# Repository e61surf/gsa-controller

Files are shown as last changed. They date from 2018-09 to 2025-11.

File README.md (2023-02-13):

# Surf System Controller - or whatever you want to control...

Feel free to make use of the hardware and software designs here for your project. It is ideally suited for robotics, small electric mobility decives, linear actuator control, or basically anything that needs to drive somewhat high-current motors and needs GPS and Bluetooth. The Atmel 32u4 based, high current board design utilizes:
3 ST Micro motor drivers,
1 Lynx GPS Module, and
1 Microchip BLE Module.

It is designed to fit into a Cinch ModeICE enclosure, which is fully waterproof.

The hardware/software design supports up to a 10 wire, 5 volt control cable and is currently utlizing 2 potentiometers, 3 momentary switches, and 3 LED indicators, but the Atmel 32u4 processor pins can be utlized for many different perposes. 

It can drive up to 3 12v motors/actuators.  Or one of the ST Micro chips can be configured as two 12v outputs for lights, horns, etc...

The board is designed to run on 12v power from a marine or automotive alternator, so it'll handle fluctuations and noise typical in rugged applications.

The BLE module and supporting AVR code supports a custom framed serial protocol for control via a mobile app.  See the documents for more info.

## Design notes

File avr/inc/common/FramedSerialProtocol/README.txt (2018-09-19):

Framed Serial Protocol Info
-------------

Message Structure (bi-directional):
Segment				Length			Notes
------------------------------------------------
Frame start			1 byte (0x7e)
Length				1 byte			Length of packet from command to end of payload inclusive
Command				1 byte
Payload				0 - 254 bytes
Checksum			1 byte			8-bit sum of all unescaped bytes from command to end of payload inclusive subtracted from 0xFF.  I.e. if if the sum is 0x02, the checksum would be 0xFD.

Note that if any byte from Length to Checksum (inclusive) matches the Frame Start or Escape bytes, then it must be escaped.
Escaping is accomplished by writing the escape character (0x7d) followed by the byte which needs escaping XOR'd with 0x20.

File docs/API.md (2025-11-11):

# SurfControl Firmware API

This document describes the public interfaces exposed by the SurfControl AVR firmware. It covers the application entry points, messaging contracts, hardware abstraction classes, and supporting utility libraries. Each section calls out responsibilities, configuration options, and example usage patterns.

## Quick Start
- **Initialization**: Call `setup()` once after reset to configure hardware, load persisted settings, and initialize communications.
- **Main loop**: Repeatedly call `loop()`; it orchestrates input sampling, actuator control, messaging, and safety logic.
- **Polling**: Every hardware abstraction (`Actuator`, `Buttons`, `Output`, `Gps`) requires periodic `poll()` calls with the elapsed milliseconds since the previous invocation.
- **Serial ISR**: Provide an `ISR(USART1_RX_vect)` that calls `serialAvr.isr()` so UART1 receive events reach the BLE link.
- **Watchdog**: The firmware expects the watchdog timer to run; `loop()` regularly resets it.

```c++
#include "SurfControl.h"

int main() {
  setup();
  while (true) {
    loop();
  }
}
```

## Application-Level API (`SurfControl.h`)

### System Configuration Constants
- **EEPROM layout**: `EEPROM_OFFSET` defines the starting address for persisted configuration; offsets 1-4 store center-motor enable, demo mode, wake-transfer delay, and actuator extension time.
- **Speed thresholds**: `MAX_SPEED` and `CENTER_EXTEND_SPEED` gate automatic tab movements based on GPS speed.
- **I/O wiring**: `BUTTON*`, `LED_*`, and `MOTOR_*` macros map AVR ports/pins to buttons, LEDs, and H-bridge channels.

### Operating Modes
- `MODE_READY` — Idle state awaiting input.
- `MODE_AUTOMATIC_CHANGE` — Automatic transitions (launch/reset/auto-trim) in progress.
- `MODE_MANUAL_RETRACT_PORT` / `MODE_MANUAL_RETRACT_STARBOARD` — Manual retraction while corresponding button combination is held.
- `MODE_MANUAL_EXTEND_PORT` / `MODE_MANUAL_EXTEND_STARBOARD` — Manual extension while button is held.

### Actuator, Direction, and Potentiometer Identifiers
- `ACTUATOR_PORT`, `ACTUATOR_STARBOARD`, `ACTUATOR_CENTER` — Select specific tab actuators when encoding BLE messages.
- `DIRECTION_DOWN`, `DIRECTION_UP` — Specify trim direction for potentiometer adjustments.
- `POT_1`, `POT_2` — Identify digital potentiometer channels when using `MSG_POT` or `MSG_POT_TRIM`.

### Message Protocol
Incoming and outgoing BLE messages use framed serial packets (see `FramedSerialProtocol`). Command identifiers and payload shapes are defined via `MSG_*` macros:

| Command | Payload | Usage |
| --- | --- | --- |
| `MSG_RESET` | none | Retract port/starboard actuators; conditionally extend center tab. |
| `MSG_LAUNCH` | none | Fully extend both actuators for launch. |
| `MSG_SURF_LEFT` / `MSG_SURF_RIGHT` | none | Enter surf mode (requires full retraction). |
| `MSG_MANUAL_RETRACT` / `MSG_MANUAL_EXTEND` | `[Actuator]` | Adjust selected actuator by ±5%. |
| `MSG_POT` | `[Pot Index][Pot Value]` | Set digital potentiometer target. |
| `MSG_POT_TRIM` | `[Pot Index][Direction]` | Trim potentiometer relative to current value. |
| `MSG_SCHEDULE_WAKE_TRANSFER` | none | Queue wake-transfer (valid in surf modes). |
| `MSG_DEBUG` | ASCII text | Emitted by firmware for diagnostics. |
| `MSG_STATE` | `[Mode][Port%][Starboard%][Center%][Pot1][Pot2][GpsLock][GpsSpeed][WakeTransferTimer]` | Periodic state broadcast; request by sending command with no data. |
| `MSG_CURRENT_SENSE` | `[PortCS][StarboardCS][CenterCS]` | Current-sense snapshot (8-bit values). |
| `MSG_GET_CONFIG` | none | Request persisted configuration; device responds with same command and 4 data bytes. |
| `MSG_SET_CONFIG` | `[CenterMotor][DemoMode][WakeTransferDelay][FullExtensionTime]` | Persist new configuration and reset MCU. |
| `MSG_LEGACY` | `[LegacyCommand]` | Compatibility command forwarded as-is. |

### Bluetooth Bootstrap
- `void bluetooth_init();` — Initializes the RN4870 BLE module to transparent serial mode. Internally issues command-mode strings via `bluetooth_command()` and drains responses.

### Entry Points
- `void setup();` — Hardware initialization, EEPROM load, analog setup, and peripheral bootstrap.
- `void loop();` — Main control loop (state machine, messaging, actuator logic).

> **Note:** `bluetooth_command()` is file-local; only `bluetooth_init()` is exposed in the header.

## Actuator Control (`Actuator.h`)

`Actuator` encapsulates a single linear actuator with PWM control and run-time tracking.

### Constructor
```c++
Actuator::Actuator(volatile uint8_t *port1,
                   uint8_t pin1,
                   volatile uint8_t *port2,
                   uint8_t pin2,
                   volatile uint8_t *portPwm,
                   uint8_t pinPwm,
                   uint8_t csAdc);
```

- `port1`/`pin1` and `port2`/`pin2` control H-bridge direction pins.
- `portPwm`/`pinPwm` drives the PWM enable line.
- `csAdc` indexes the analog current-sense channel.
- Automatically configures DDR and sets outputs low; initializes full-extension time to 3.5 s.

### Runtime API
- `void poll(uint16_t elapsed_ms);` — Drives the H-bridge according to pending extend/retract durations or manual override, using elapsed time since the previous call.
- `void set_extension(int8_t percent);` — Schedule actuator to reach a target position (0–100%). Clamps input, compensates for motor spin-up, and adjusts calibration when operating at limits.
- `void adjust_extension(int8_t delta_percent);` — Convenience wrapper around `set_extension(get_extension() + delta_percent)`.
- `uint8_t get_extension();` — Estimates current extension (0 or 100 returned when near extremes, otherwise 5–98% range).
- `void set_manual_movement(int8_t movement);` — Direct control: `1` extends, `-1` retracts, `0` disables manual override. Manual motion continues until cleared.
- `int32_t get_outstanding_time();` — Remaining movement in milliseconds (positive for extension, negative for retraction).
- `uint32_t get_full_extension_time();` / `void set_full_extension_time(uint16_t ms);` — Retrieve or configure travel time (clamped to 3000–8000 ms).

### Usage Example
```c++
Actuator trim(&PORTB, 2, &PORTB, 3, &PORTD, 6, POT1_ADC);

void service_actuator(uint16_t elapsed_ms) {
  trim.poll(elapsed_ms);
  if (need_full_extension && trim.get_extension() < 95) {
    trim.set_extension(100);
  }
}
```

## Button Handling (`Buttons.h`)

`Buttons` debounces and classifies up to three physical buttons.

### Constructor
```c++
Buttons::Buttons(volatile uint8_t *port1, uint8_t pin1,
                 volatile uint8_t *port2, uint8_t pin2,
                 volatile uint8_t *port3, uint8_t pin3);
```

- Configures pins as inputs with pull-ups.
- Button indices (`BUTTON_SURF_LEFT`, `BUTTON_RESET`, `BUTTON_SURF_RIGHT`) map into the event masks returned by accessors.

### Polling & Queries
- `void poll(uint16_t elapsed_ms);` — Sample inputs, update timers, and derive edge/hold states.
- `uint8_t falling_edge();` — Buttons newly pressed (held longer than `PRESS_TIME` without prior release).
- `uint8_t rising_edge();` — Buttons newly released after a qualifying press.
- `uint8_t longpressed();` — Buttons surpassing `LONGPRESS_TIME` without release.
- `uint8_t held();` — Buttons currently held beyond long-press threshold; used for continuous manual modes.

### Usage Example
```c++
Buttons controls(&PORTF, 0, &PORTB, 0, &PORTB, 1);

void service_buttons(uint16_t elapsed_ms) {
  controls.poll(elapsed_ms);
  if (controls.falling_edge() & _BV(BUTTON_RESET)) {
    trigger_reset_sequence();
  }
  if (controls.held() & _BV(BUTTON_SURF_LEFT)) {
    actuatorPort.set_manual_movement(1);
  }
}
```

## Output Control (`Output.h`)

`Output` manages a single digital output with on/off/flash states.

- Constructor: `Output(volatile uint8_t *port, uint8_t pin);` — Sets DDR and initializes pin low.
- `void poll(uint16_t elapsed_ms);` — Applies current flash state: off (`0x0000`), solid on (`0xFFFF`), or toggling at configured interval.
- `void on();`, `void off();`, `void flash(uint16_t interval_ms);` — Queue desired state changes, applied on next `poll()`.

### Usage Example
```c++
Output statusLed(&PORTB, 7);

void indicate_status(uint16_t elapsed_ms, bool critical) {
  if (critical) statusLed.flash(200);
  else statusLed.on();
  statusLed.poll(elapsed_ms);
}
```

## GPS Wrapper (`Gps.h`)

Provides a thin layer over `TinyGPS` for speed and lock status tracking.

- Constructor: `Gps();` (the actual serial configuration must occur in user code).
- `void poll(uint16_t elapsed_ms);` — Reads bytes via `software_serial_*` helpers, feeds the TinyGPS parser, and tracks time since last valid sentence (`GPS_TIMEOUT` defines the lock threshold).
- `uint8_t get_locked();` — Returns `1` when valid sentences arrive within timeout, `0` otherwise. Always `1` in demo mode.
- `uint8_t get_speed();` — Last parsed speed in knots (integer). Returns `9` in demo mode.

### Usage Example
```c++
Gps gps;

void update_gps(uint16_t elapsed_ms) {
  gps.poll(elapsed_ms);
  if (!gps.get_locked()) {
    enter_fail_safe();
  }
}
```

## Analog Utilities (`lib/analog/analog.h`)

- `void analog_init(uint8_t analog_pins[], uint8_t count, uint8_t aref);` — Configure ADC channels. `aref` accepts `ANALOG_AREF`, `ANALOG_AVCC`, or `ANALOG_INTERNAL_256` constants.
- `void analog_read_a(uint16_t *buffer);` — Fill `buffer` with current values for the configured channel sequence.
- `uint16_t analog_read_p(uint8_t index);` — Read a single configured channel synchronously.

Ensure `F_CPU` matches the MCU clock (16 MHz in this project) so default prescaler values yield accurate conversions.

## Timer Utilities (`lib/timer/timer.h`)

- `void timer_init();` — Configure Timer1 in CTC mode for 1 kHz interrupts (automatic `sei()` unless `NO_INTERRUPT_ENABLE` is defined).
- `uint32_t timer_millis();` — Milliseconds since initialization (wraps ~49 days).
- `uint32_t timer_micros();` — Microseconds since initialization (wraps ~71 minutes).

Use `timer_millis()` to compute elapsed times for `poll()` calls.

## Software Serial (`lib/serial/software_serial.h`)

Implements half-duplex software UART on PD0 (TX) / PD1 (RX) with interrupt-driven receive.

- `void software_serial_init(uint32_t baud);` — Supported baud rates: 9600 (default) or 115200 (TX only). Requires 16 MHz system clock.
- `uint8_t software_serial_read_b(uint8_t *byte);` — Non-blocking read; returns 1 when a byte is available.
- `void software_serial_write_a(uint8_t *data, uint8_t len);` — Blocking write of a byte buffer.
- `uint8_t software_serial_write_b(uint8_t data);` — Blocking single-byte write.
- `uint8_t software_serial_available();` — Returns non-zero when receive buffer contains data.

Example: Poll within the GPS service loop before feeding characters to `TinyGPS`.

## Hardware Serial (`inc/avr/Serial/SerialAVR.h`)

`digitalcave::SerialAVR` adapts AVR hardware UARTs to the `Stream` interface.

- Constructor signature:
  ```c++
  SerialAVR(uint32_t baud,
            uint8_t dataBits = 8,
            uint8_t parity = 0,
            uint8_t stopBits = 1,
            uint8_t serialPort = 0,
            uint8_t bufferSize = 64);
  ```
  - `serialPort`: 0 → USART0, 1 → USART1 (additional ports can be added).
  - Constructor enables RX interrupts and TX output using double-speed mode when beneficial.
- `uint8_t read(uint8_t *b);` — Non-blocking; disables RX interrupt temporarily to protect the ring buffer.
- `uint8_t write(uint8_t data);` — Blocking transmit.
- `void isr();` — Must be invoked from the corresponding UART RX ISR to push incoming bytes into the buffer.

### Usage Example
```c++
SerialAVR serialAvr(115200, 8, 0, 1, 1, 128);

ISR(USART1_RX_vect) {
  serialAvr.isr();
}
```

## USB Serial (`inc/avr/Serial/SerialUSB.h`)

`digitalcave::SerialUSB` exposes CDC ACM over USB (Teensy-compatible implementation).

- Constructor: `SerialUSB();` — Configures USB hardware, enables interrupts, and starts the CDC stack.
- `uint8_t isConnected();` — Non-zero when USB host has enumerated the device.
- `uint8_t available();` — Count of buffered bytes in RX endpoint.
- `void flushInput();`, `void flushOutput();` — Clear buffers and force immediate transmission.
- `uint8_t read(uint8_t *b);`, `uint8_t write(uint8_t data);`, `uint8_t write(uint8_t* data, uint8_t len);` — Stream operations (all non-blocking for reads, blocking for writes as required by USB semantics).

Standalone C helpers (e.g., `usb_init`, `usb_serial_write_b`) mirror PJRC's API for legacy code.

## Stream Abstractions (`inc/common/Stream`)

- `digitalcave::Stream` — Abstract base class defining `read(uint8_t*)` and `write(uint8_t)` plus utility overloads:
  - `uint8_t read(uint8_t* buffer, uint8_t len);`
  - `uint8_t write(char* data);`
  - `uint8_t write(const char* data);`
  - `uint8_t write(uint8_t* data, uint8_t len);`

- `digitalcave::ArrayStream` — Ring buffer implementation:
  - `ArrayStream(uint8_t capacity);`, `~ArrayStream();`
  - `uint8_t read(uint8_t *b);`, `uint8_t write(uint8_t b);`
  - Buffer status helpers: `remaining()`, `size()`, `isEmpty()`, `isFull()`.

- `digitalcave::NullStream` — Sink/source that drops all writes and never yields data; useful for optional logging targets.

## Framed Serial Protocol (`inc/common/FramedSerialProtocol`)

Encapsulates HDLC-like framing with byte stuffing for robust transport over `Stream` instances.

### `digitalcave::FramedSerialMessage`
- Constructors:
  - `FramedSerialMessage(uint8_t command, uint8_t maxSize);` — Allocate writable frame buffer.
  - `FramedSerialMessage(uint8_t command, uint8_t* message, uint8_t length);` — Wrap existing payload (used internally).
- Destructor frees owned buffer.
- `void clone(FramedSerialMessage* other);` — Copy command/data/length into current instance.
- Accessors: `uint8_t getCommand();`, `uint8_t getLength();`, `uint8_t* getData();`.
- `void append(uint8_t byte);` — Append payload bytes.

### `digitalcave::FramedSerialProtocol`
- Constructor: `FramedSerialProtocol(uint8_t maxPayload);` — Allocate receive buffer and clear state.
- `uint8_t read(Stream* transport, FramedSerialMessage* result);` — Consume bytes, return `1` when a full frame is decoded, and populate `result`.
- `void write(Stream* transport, FramedSerialMessage* message);` — Emit a framed packet with escaping and checksum.
- `uint8_t getError();` — Retrieve the last decoder error (`NO_ERROR` when clear).

### Usage Example
```c++
FramedSerialProtocol protocol(64);
FramedSerialMessage request(0, 64);

if (protocol.read(&serialAvr, &request)) {
  handle_command(request.getCommand(), request.getData(), request.getLength());
}

FramedSerialMessage response(MSG_STATE, 9);
response.append(mode);
response.append(actuatorPort.get_extension());
// ... populate remaining bytes ...
protocol.write(&serialAvr, &response);
```

## TinyGPS Wrapper (`lib/tinygps/TinyGPS.h`)

`TinyGPS` is a third-party library included in the repository. Key public methods:
- `bool encode(char c);` — Feed NMEA stream one character at a time.
- `void get_position(long *latitude, long *longitude, unsigned long *fix_age = 0);`
- `void get_datetime(unsigned long *date, unsigned long *time, unsigned long *age = 0);`
- `long altitude();`, `unsigned long speed();`, `unsigned long course();`
- Float helpers: `f_get_position`, `f_speed_kmph`, `f_course`, etc.
- Static utilities: `distance_between`, `course_to`, `cardinal`.

Consult the upstream TinyGPS documentation for comprehensive coverage; this codebase primarily uses `encode()` and `speed()`.

## DigitalCave Utilities (`inc/common/dcutil`)

- `dcmath.h`: Lookup-table trigonometric helpers (`acos_f`, `cos_f`, `sin_f`), integer square root (`sqrt_f`), and fast inverse square root (`invSqrt`).
- `delay.h`: Busy-wait delay helpers `delay_ms(uint32_t)` and `delay_us(uint32_t)` (preserve interrupts).
- `persist.h`: Abstract persistent storage reads/writes (`persist_write`, `persist_read`) returning zero on success.

These utilities are C-friendly with `extern "C"` guards for optional C++ builds.

## Putting It Together

```c++
#include "SurfControl.h"
#include "Actuator.h"
#include "Buttons.h"
#include "Output.h"
#include "Gps.h"
#include <FramedSerialProtocol.h>

using namespace digitalcave;

Actuator port(...);
Buttons buttons(...);
Output status(...);
Gps gps;
FramedSerialProtocol protocol(64);
FramedSerialMessage inbound(0, 64);

void loop_once() {
  static uint32_t last_ms = timer_millis();
  uint32_t now = timer_millis();
  uint16_t elapsed = now - last_ms;
  last_ms = now;

  port.poll(elapsed);
  buttons.poll(elapsed);
  status.poll(elapsed);
  gps.poll(elapsed);

  if (protocol.read(&serialAvr, &inbound)) {
    handle_command(inbound);
  }
}
```

This example highlights the polling model shared across the firmware: capture elapsed time via `timer_millis()`, service each peripheral, and process framed serial commands as they arrive.

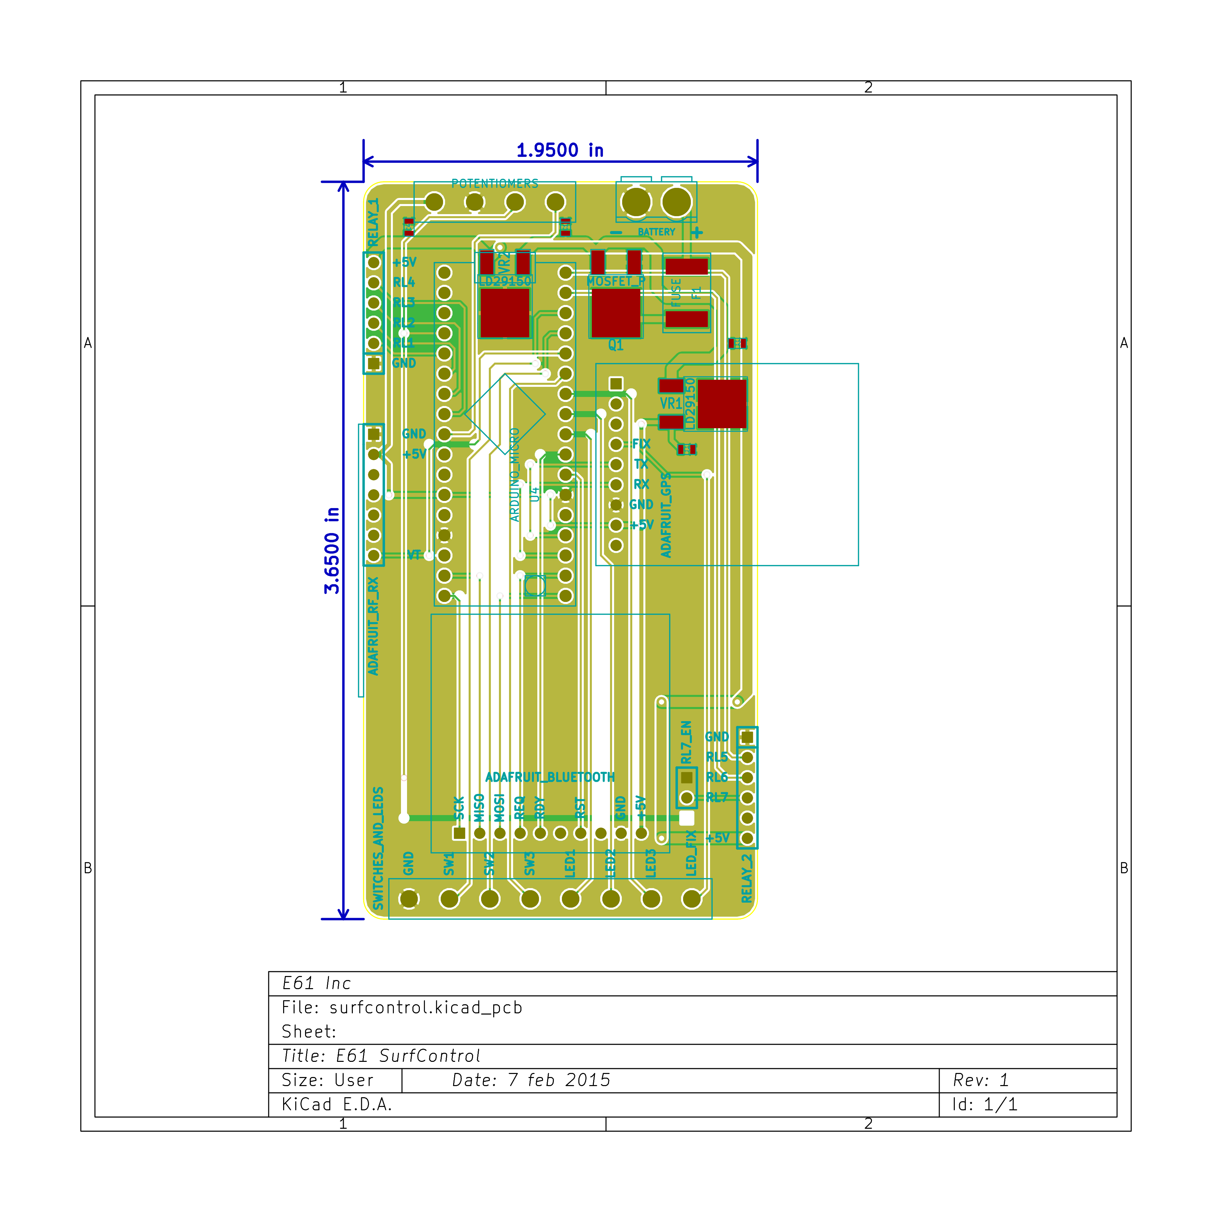
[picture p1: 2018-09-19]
kicad/surfcontrol--brd.png

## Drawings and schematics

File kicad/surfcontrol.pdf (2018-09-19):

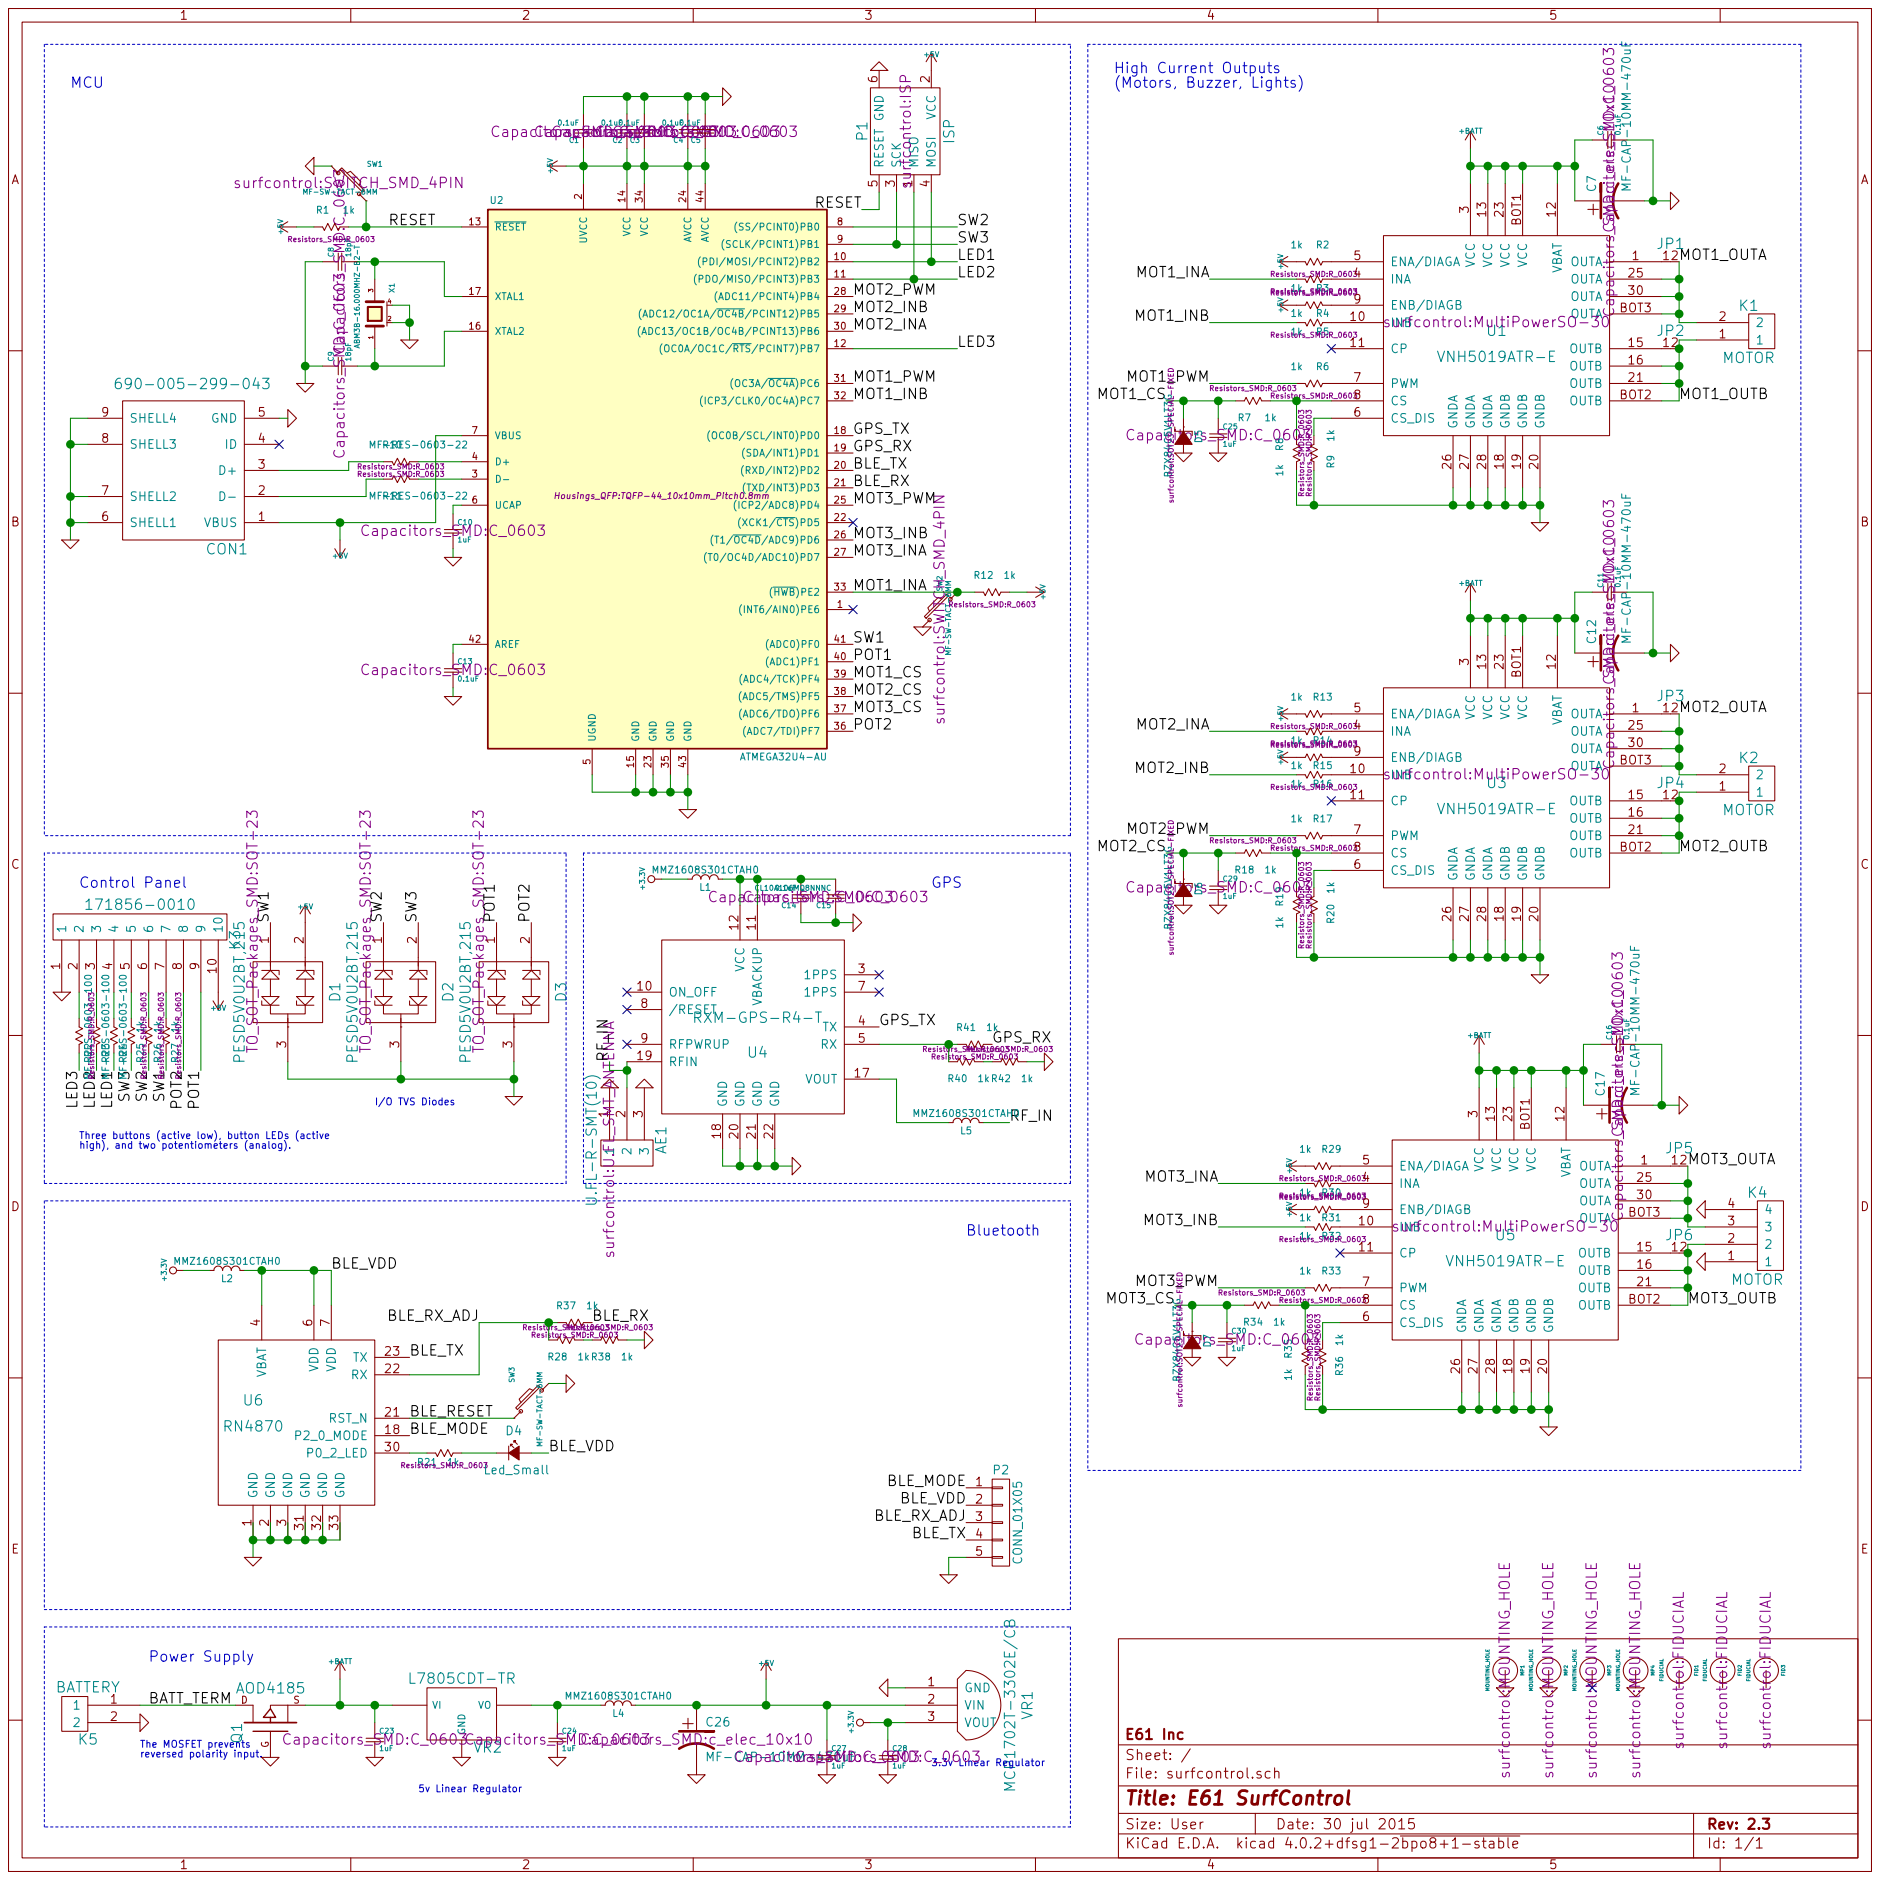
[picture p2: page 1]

3 D3 PESD5V0U2BT,215 TO_SOT_Packages_SMD:SOT-23 POT1 MP4 MOUNTING_HOLE surfcontrol:MOUNTING_HOLE MP3 MOUNTING_HOLE surfcontrol:MOUNTING_HOLE MP2 MOUNTING_HOLE surfcontrol:MOUNTING_HOLE MP1 MOUNTING_HOLE surfcontrol:MOUNTING_HOLE

+5V Three buttons (active low), button LEDs (active

7 P0_2_LED 30 RST_N 21 GND 31 RX 22 GND 32 TX 23 GND 33 P2_0_MODE 18 U6 RN4870

Id: 1/1 Title: E61 SurfControl File: surfcontrol.sch Sheet: / E61 Inc Power Supply

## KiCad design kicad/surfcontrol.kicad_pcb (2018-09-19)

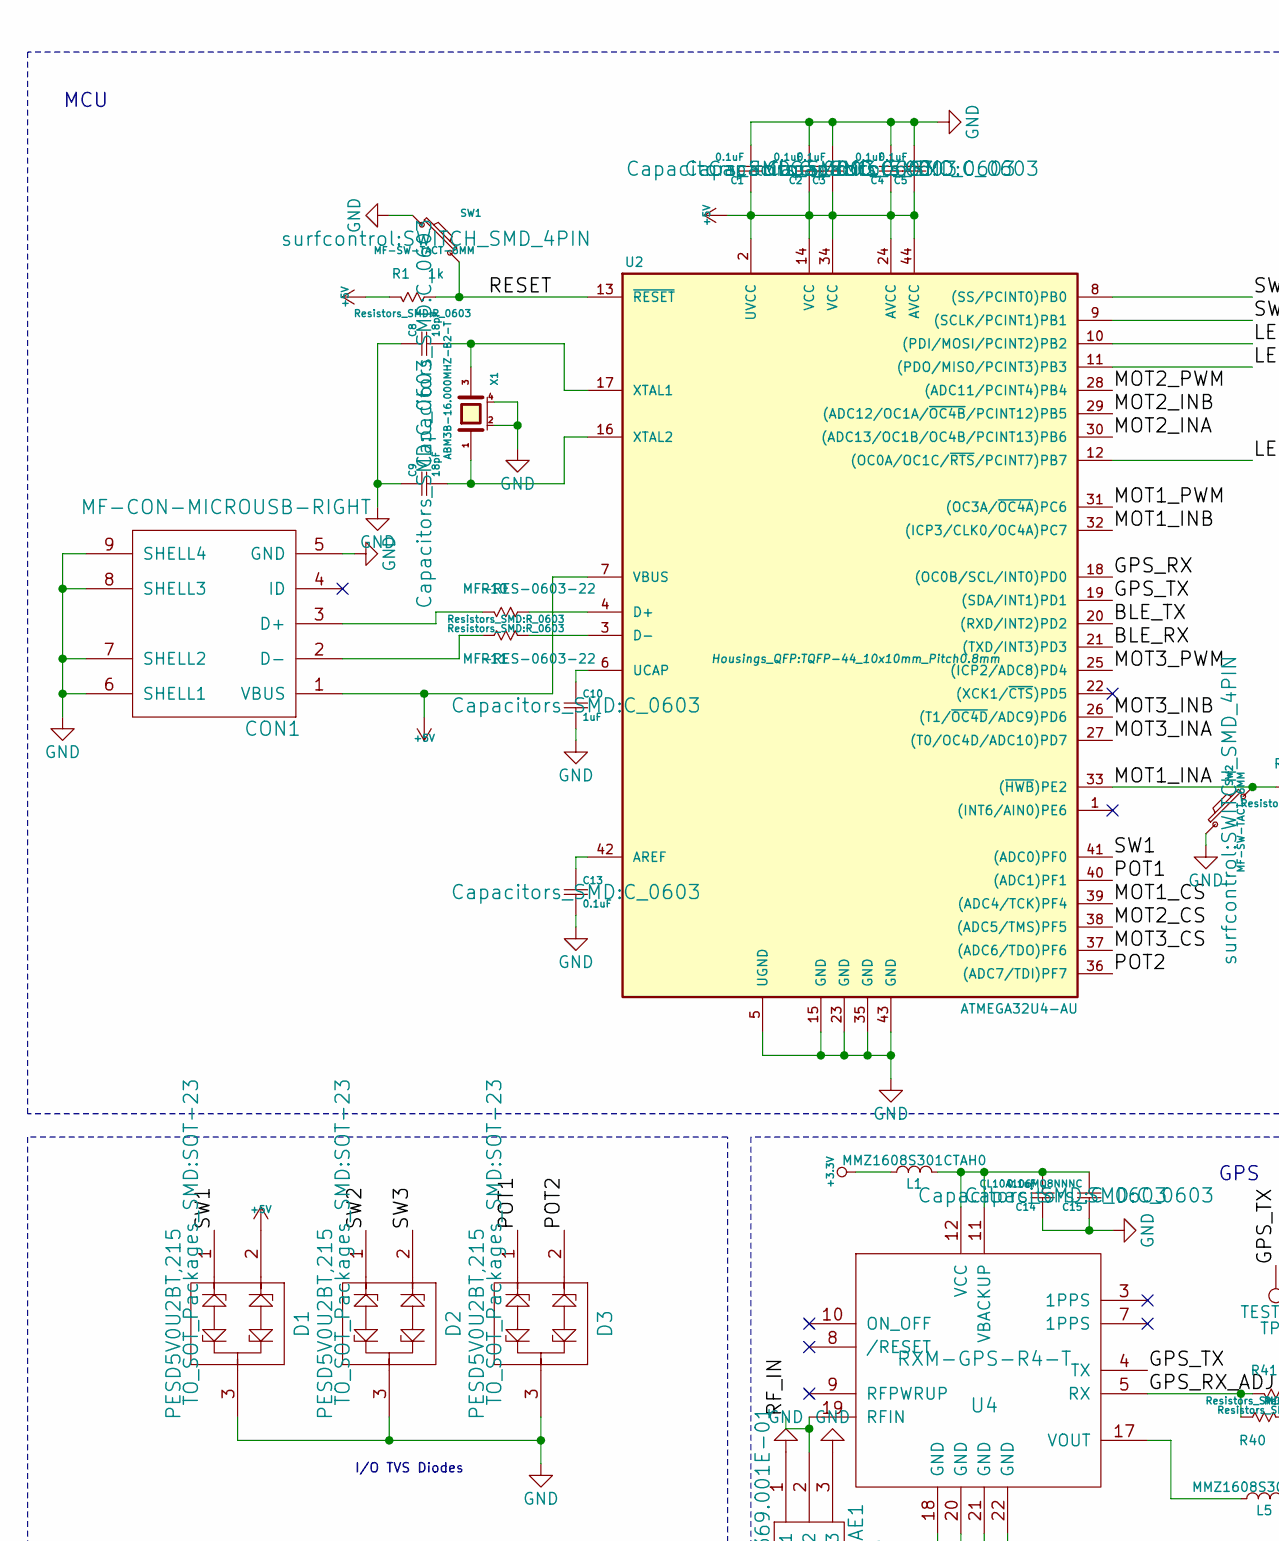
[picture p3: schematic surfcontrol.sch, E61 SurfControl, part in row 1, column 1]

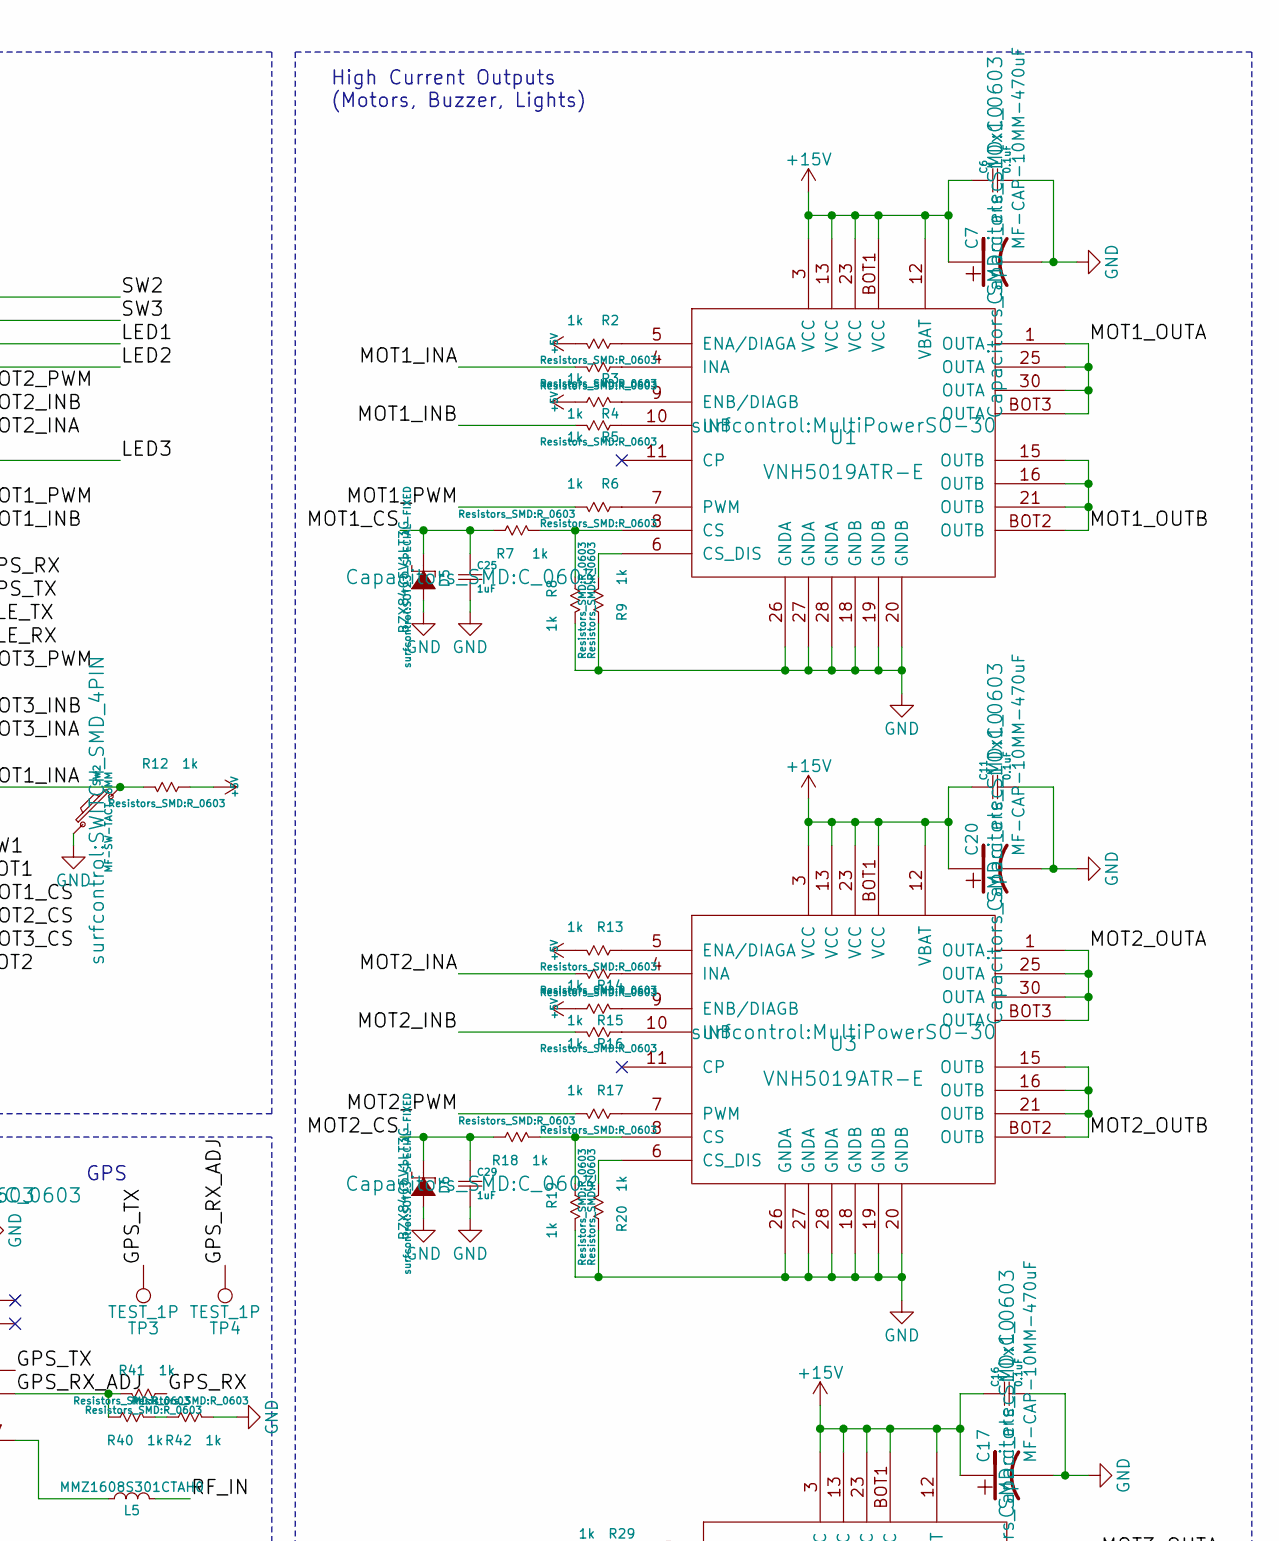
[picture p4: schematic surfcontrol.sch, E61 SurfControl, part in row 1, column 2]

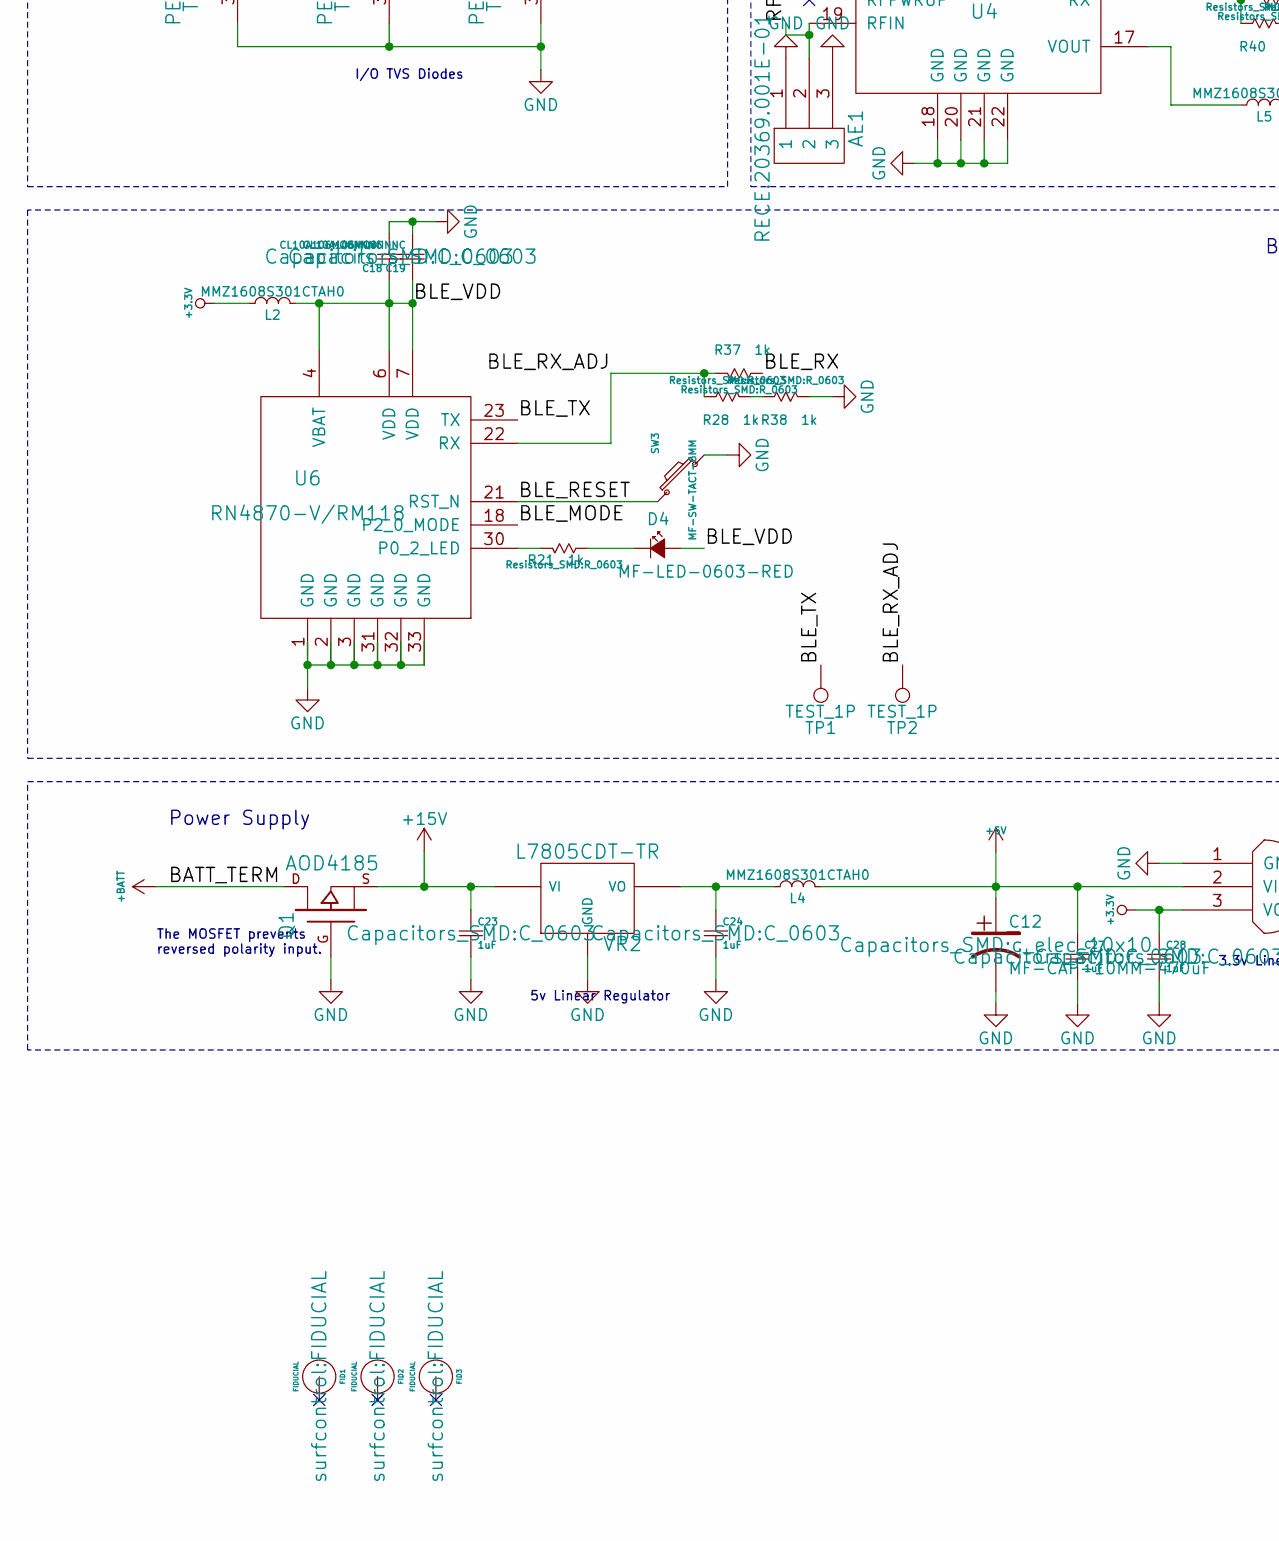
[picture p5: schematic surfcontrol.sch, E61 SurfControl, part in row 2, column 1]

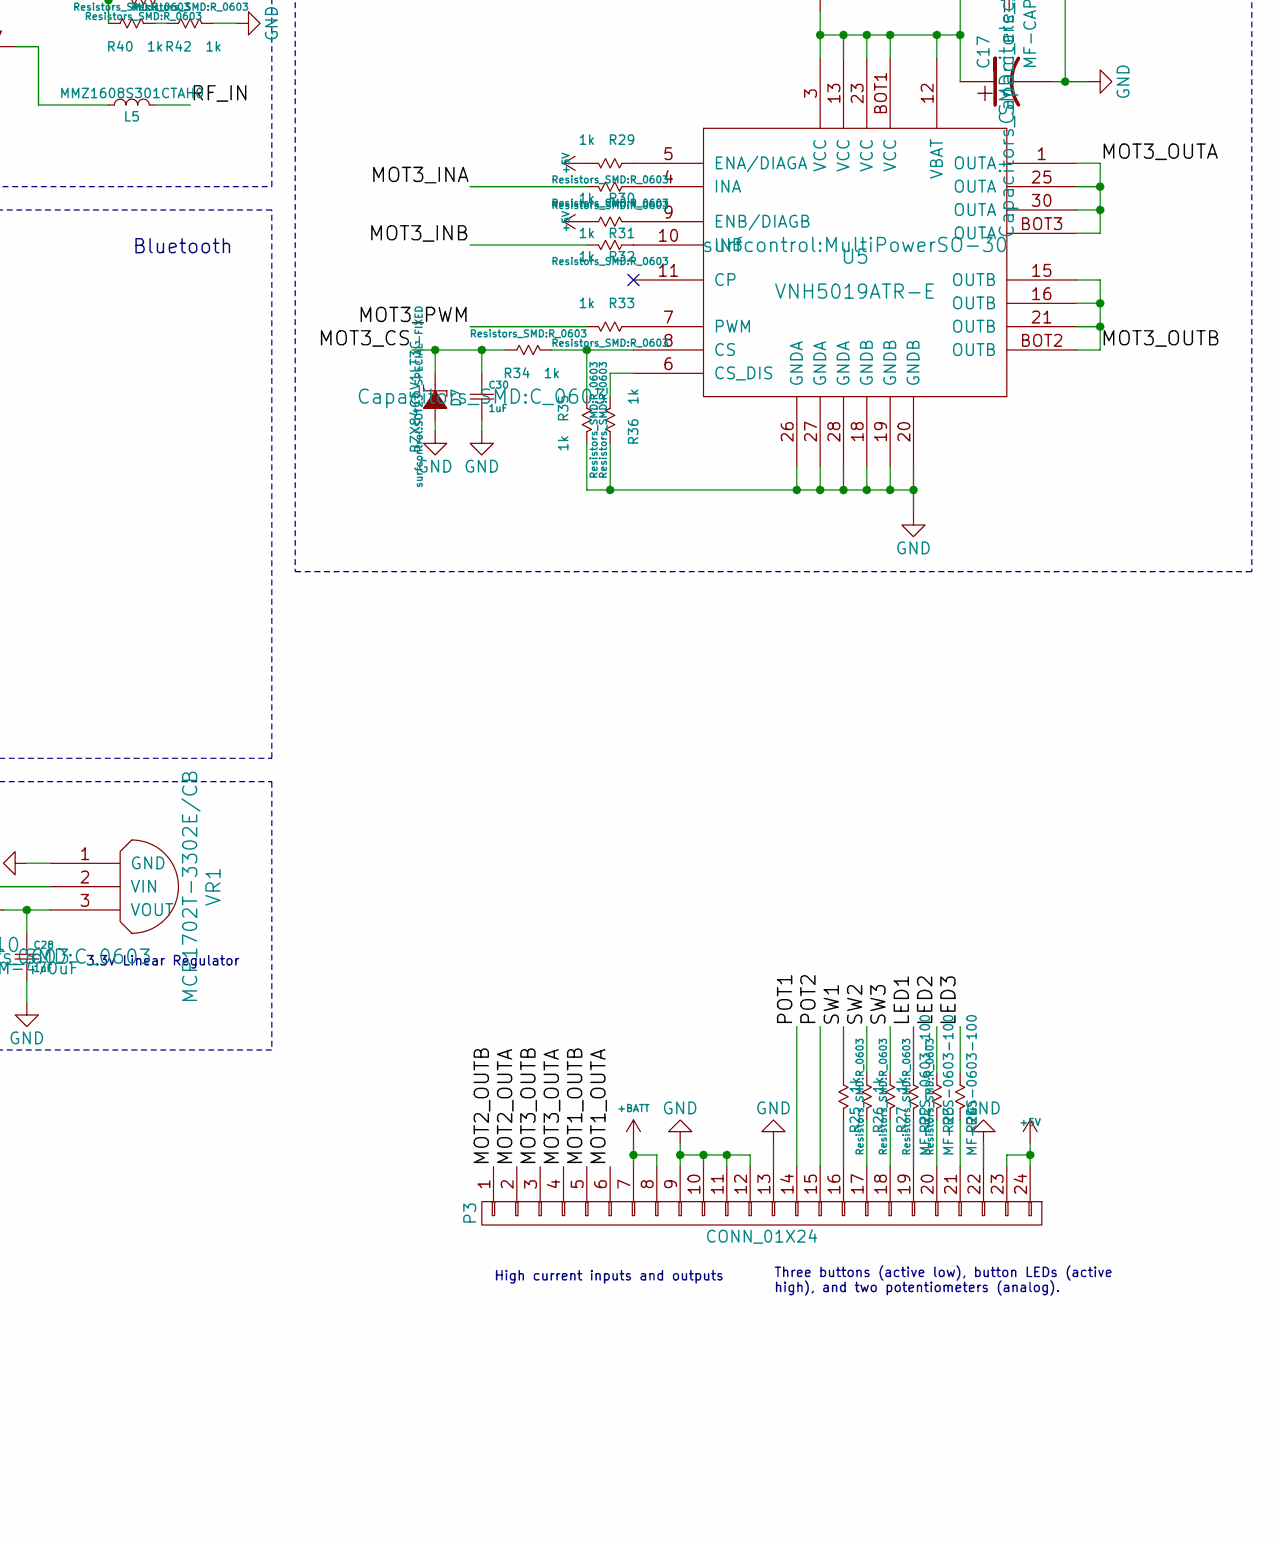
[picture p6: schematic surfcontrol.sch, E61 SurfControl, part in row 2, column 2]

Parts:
AE1: RECE.20369.001E-01; MHF_III; Digikey 931-1157-2-ND
C1, C2, C3, C4, C5, C6, C11, C13, C14, C16: 0.1uF; C_0603; Digikey 1276-1012-1-ND
C7, C12, C17, C20: MF-CAP-10MM-470uF; c_elec_10x10; Digikey Part# 493-6225-2-ND
C8, C9: 18pF; C_0603; Digikey 1276-1089-1-ND
C10, C23, C24, C25, C27, C28, C29, C30: 1uF; C_0603; Digikey 311-1445-1-ND
C15, C18, C19: CL10A106MQ8NNNC; C_0603; Digikey 1276-1119-1-ND
CON1: MF-CON-MICROUSB-RIGHT; USB_Micro-B_SMD; Digikey 151-1206-1-ND
D1, D2, D3: PESD5V0U2BT,215; SOT-23; Digikey 568-4296-1-ND
D4: MF-LED-0603-RED; LED_0603
D5, D6, D7: BZX84C5V1LT3G; SOT23-SPECIAL-FIXED; Digikey BZX84C5V1LT3GOSCT-ND
FID1, FID2, FID3: FIDUCIAL
L1, L2, L4, L5: MMZ1608S301CTAH0; SM0603_VALUE; Digikey 445-172727-1-ND
P3: CONN_01X24; CINCH_MODICE_ME-MX_24POS
Q1: AOD4185; TO-252-2Lead; Digikey 785-1222-1-ND
R1, R2, R3, R4, R5, R6, R7, R8, R9, R12, R13, R14, R15, R16, R17, R18, R19, R20, R21, R25, R26, R27, R28, R29, R30, R31, R32, R33, R34, R35, R36, R37, R38, R40, R41, R42: 1k; R_0603; Digikey RHM1.0KCGCT-ND
R10, R11: MF-RES-0603-22; R_0603; Digikey RHM22CGCT-ND
R22, R23, R24: MF-RES-0603-100; R_0603; Digikey RHM100CGCT-ND
SW1, SW2, SW3: MF-SW-TACT-6MM; SWITCH_SMD_4PIN; Digikey P12961SCT-ND
TP1, TP2, TP3, TP4: TEST_1P; Pin_Header_Straight_1x01
U1, U3, U5: VNH5019ATR-E; MultiPowerSO-30; Digikey 497-13073-1-ND
U2: ATMEGA32U4-AU; TQFP-44_10x10mm_Pitch0.8mm; Digikey Part# ATMEGA32U4-AU-ND
U4: RXM-GPS-R4-T; R4_SERIES_GPS; Digikey RXM-GPS-R4-TCT-ND
U6: RN4870-V/RM118; RN4870
VR1: MCP1702T-3302E/CB; SOT23-SPECIAL-FIXED; Digikey MCP1702T-3302E/CBCT-ND
VR2: L7805CDT-TR; TO-252-2Lead; Digikey Part# 497-7255-1-ND
X1: ABM3B-16.000MHZ-B2-T; crystal_smd_5x3.2; Digikey 535-9122-1-ND

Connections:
+3.3V: C28.1, L1.1, L2.1, VR1.3 (VOUT)
+5V: C1.1, C2.1, C3.1, C4.1, C5.1, C12.1, C27.1, CON1.1 (VBUS), D1.2, L4.2, P3.23, P3.24, R1.2, R2.1, R4.1, R12.1, R13.1, R15.1, R29.1, R31.1, U2.2 (UVCC), U2.7 (VBUS), U2.14 (VCC), U2.24 (AVCC), U2.34 (VCC), U2.44 (AVCC), VR1.2 (VIN)
+15V: C6.1, C7.1, C11.1, C16.1, C17.1, C20.1, C23.1, Q1.S, U1.3 (VCC), U1.12 (VBAT), U1.13 (VCC), U1.23 (VCC), U1.BOT1 (VCC), U3.3 (VCC), U3.12 (VBAT), U3.13 (VCC), U3.23 (VCC), U3.BOT1 (VCC), U5.3 (VCC), U5.12 (VBAT), U5.13 (VCC), U5.23 (VCC), U5.BOT1 (VCC), VR2.VI
+BATT: P3.7, P3.8, Q1.D
/BLE_MODE: U6.18 (P2_0_MODE)
/BLE_RESET: SW3.1, U6.21 (RST_N)
/BLE_RX: R37.1, U2.21 ((TXD/INT3)PD3)
/BLE_RX_ADJ: R28.2, R37.2, TP2.1, U6.22 (RX)
/BLE_TX: TP1.1, U2.20 ((RXD/INT2)PD2), U6.23 (TX)
/BLE_VDD: C18.1, C19.1, D4.2 (A), L2.2, U6.4 (VBAT), U6.6 (VDD), U6.7 (VDD)
/GPS_RX: R41.1, U2.18 ((OC0B/SCL/INT0)PD0)
/GPS_RX_ADJ: R40.2, R41.2, TP4.1, U4.5 (RX)
/GPS_TX: TP3.1, U2.19 ((SDA/INT1)PD1), U4.4 (TX)
/LED1: R22.1, U2.10 ((PDI/MOSI/PCINT2)PB2)
/LED2: R23.1, U2.11 ((PDO/MISO/PCINT3)PB3)
/LED3: R24.1, U2.12 ((OC0A/OC1C/~RTS~/PCINT7)PB7)
/MOT1_CS: C25.1, D5.2 (K), R7.2, U2.39 ((ADC4/TCK)PF4)
/MOT1_INA: R3.1, R12.2, SW2.2, U2.33 ((~HWB~)PE2)
/MOT1_INB: R5.1, U2.32 ((ICP3/CLK0/OC4A)PC7)
/MOT1_OUTA: P3.6, U1.1 (OUTA), U1.25 (OUTA), U1.30 (OUTA), U1.BOT3 (OUTA)
/MOT1_OUTB: P3.5, U1.15 (OUTB), U1.16 (OUTB), U1.21 (OUTB), U1.BOT2 (OUTB)
/MOT1_PWM: R6.1, U2.31 ((OC3A/~OC4A~)PC6)
/MOT2_CS: C29.1, D6.2 (K), R18.2, U2.38 ((ADC5/TMS)PF5)
/MOT2_INA: R14.1, U2.30 ((ADC13/OC1B/OC4B/PCINT13)PB6)
/MOT2_INB: R16.1, U2.29 ((ADC12/OC1A/~OC4B~/PCINT12)PB5)
/MOT2_OUTA: P3.2, U3.1 (OUTA), U3.25 (OUTA), U3.30 (OUTA), U3.BOT3 (OUTA)
/MOT2_OUTB: P3.1, U3.15 (OUTB), U3.16 (OUTB), U3.21 (OUTB), U3.BOT2 (OUTB)
/MOT2_PWM: R17.1, U2.28 ((ADC11/PCINT4)PB4)
/MOT3_CS: C30.1, D7.2 (K), R34.2, U2.37 ((ADC6/TDO)PF6)
/MOT3_INA: R30.1, U2.27 ((T0/OC4D/ADC10)PD7)
/MOT3_INB: R32.1, U2.26 ((T1/~OC4D~/ADC9)PD6)
/MOT3_OUTA: P3.4, U5.1 (OUTA), U5.25 (OUTA), U5.30 (OUTA), U5.BOT3 (OUTA)
/MOT3_OUTB: P3.3, U5.15 (OUTB), U5.16 (OUTB), U5.21 (OUTB), U5.BOT2 (OUTB)
/MOT3_PWM: R33.1, U2.25 ((ICP2/ADC8)PD4)
/POT1: D3.1, P3.14, U2.40 ((ADC1)PF1)
/POT2: D3.2, P3.15, U2.36 ((ADC7/TDI)PF7)
/RESET: R1.1, SW1.2, U2.13 (~RESET~)
/RF_IN: AE1.2, L5.1, U4.19 (RFIN)
/SW1: D1.1, R25.1, U2.41 ((ADC0)PF0)
/SW2: D2.1, R26.1, U2.8 ((SS/PCINT0)PB0)
/SW3: D2.2, R27.1, U2.9 ((SCLK/PCINT1)PB1)
GND: AE1.1, AE1.3, C1.2, C2.2, C3.2, C4.2, C5.2, C6.2, C7.2, C8.1, C9.1, C10.2, C11.2, C12.2, C13.2, C14.1, C15.1, C16.2, C17.2, C18.2, C19.2, C20.2, C23.2, C24.2, C25.2, C27.2, C28.2, C29.2, C30.2, CON1.5 (GND), CON1.6 (SHELL1), CON1.7 (SHELL2), CON1.8 (SHELL3), CON1.9 (SHELL4), D1.3, D2.3, D3.3, D5.1 (A), D6.1 (A), D7.1 (A), P3.9, P3.10, P3.11, P3.12, P3.13, P3.22, Q1.G, R8.1, R9.2, R19.1, R20.2, R35.1, R36.2, R38.1, R42.1, SW1.1, SW2.1, SW3.2, U1.18 (GNDB), U1.19 (GNDB), U1.20 (GNDB), U1.26 (GNDA), U1.27 (GNDA), U1.28 (GNDA), U2.5 (UGND), U2.15 (GND), U2.23 (GND), U2.35 (GND), U2.43 (GND), U3.18 (GNDB), U3.19 (GNDB), U3.20 (GNDB), U3.26 (GNDA), U3.27 (GNDA), U3.28 (GNDA), U4.18 (GND), U4.20 (GND), U4.21 (GND), U4.22 (GND), U5.18 (GNDB), U5.19 (GNDB), U5.20 (GNDB), U5.26 (GNDA), U5.27 (GNDA), U5.28 (GNDA), U6.1 (GND), U6.2 (GND), U6.3 (GND), U6.31 (GND), U6.32 (GND), U6.33 (GND), VR1.1 (GND), VR2.GND, X1.2, X1.4
unnamed: C8.2, U2.17 (XTAL1), X1.3
unnamed: C9.2, U2.16 (XTAL2), X1.1
unnamed: C10.1, U2.6 (UCAP)
unnamed: C13.1, U2.42 (AREF)
unnamed: C14.2, C15.2, L1.2, U4.11 (VBACKUP), U4.12 (VCC)
unnamed: C24.1, L4.1, VR2.VO
unnamed: CON1.2 (D-), R11.2
unnamed: CON1.3 (D+), R10.2
unnamed: D4.1 (K), R21.1
unnamed: L5.2, U4.17 (VOUT)
unnamed: P3.16, R25.2
unnamed: P3.17, R26.2
unnamed: P3.18, R27.2
unnamed: P3.19, R22.2
unnamed: P3.20, R23.2
unnamed: P3.21, R24.2
unnamed: R2.2, U1.5 (ENA/DIAGA)
unnamed: R3.2, U1.4 (INA)
unnamed: R4.2, U1.9 (ENB/DIAGB)
unnamed: R5.2, U1.10 (INB)
unnamed: R6.2, U1.7 (PWM)
unnamed: R7.1, R8.2, U1.8 (CS)
unnamed: R9.1, U1.6 (CS_DIS)
unnamed: R10.1, U2.4 (D+)
unnamed: R11.1, U2.3 (D-)
unnamed: R13.2, U3.5 (ENA/DIAGA)
unnamed: R14.2, U3.4 (INA)
unnamed: R15.2, U3.9 (ENB/DIAGB)
unnamed: R16.2, U3.10 (INB)
unnamed: R17.2, U3.7 (PWM)
unnamed: R18.1, R19.2, U3.8 (CS)
unnamed: R20.1, U3.6 (CS_DIS)
unnamed: R21.2, U6.30 (P0_2_LED)
unnamed: R28.1, R38.2
unnamed: R29.2, U5.5 (ENA/DIAGA)
unnamed: R30.2, U5.4 (INA)
unnamed: R31.2, U5.9 (ENB/DIAGB)
unnamed: R32.2, U5.10 (INB)
unnamed: R33.2, U5.7 (PWM)
unnamed: R34.1, R35.2, U5.8 (CS)
unnamed: R36.1, U5.6 (CS_DIS)
unnamed: R40.1, R42.2

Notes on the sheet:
Power Supply
Three buttons (active low), button LEDs (active high), and two potentiometers (analog).
The MOSFET prevents reversed polarity input.
I/O TVS Diodes
5v Linear Regulator
3.3v Linear Regulator
High Current Outputs (Motors, Buzzer, Lights)
GPS
MCU
Bluetooth
High current inputs and outputs

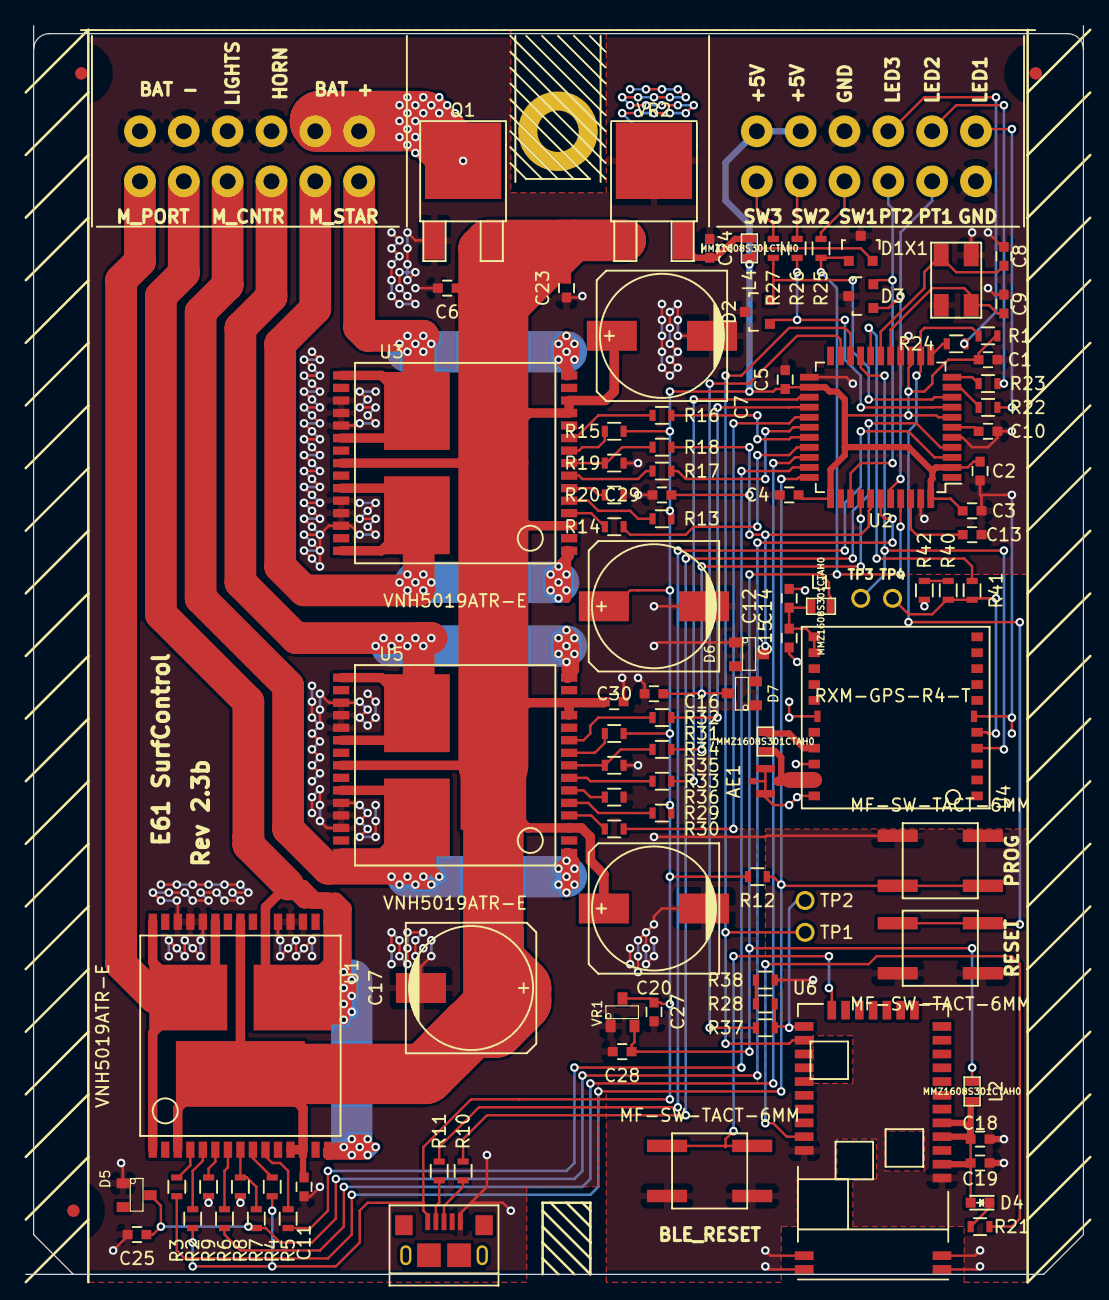
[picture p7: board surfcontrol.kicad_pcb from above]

Board: 2 copper layers, 84.5 x 99.7 mm, 102 parts (0 on the bottom side), 83 nets.

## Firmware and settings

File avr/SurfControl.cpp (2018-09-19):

/*

This software is the property of E61 Incorporated. All use of any part of this software is prohibited without the express written consent of E61 Incorporated.

*/

#include <math.h>
#include <stdio.h>
#include <avr/eeprom.h>
#include <util/delay.h>
#include <avr/wdt.h>
#include <avr/power.h>

#include "SurfControl.h"

#include <dcmath.h>
#include <FramedSerialProtocol.h>
#include <SerialAVR.h>
#include <SerialUSB.h>

#include "lib/analog/analog.h"
#include "lib/timer/timer.h"
#include "lib/serial/software_serial.h"

#include "Actuator.h"
#include "Buttons.h"
#include "Gps.h"
#include "Output.h"

//GPS wrapper uses Serial1
Gps gps;

using namespace digitalcave;

//Instantiate actuator control objects
Actuator actuatorPort(&MOTOR_PORT_PORT1, MOTOR_PORT_PIN1, &MOTOR_PORT_PORT2, MOTOR_PORT_PIN2, &MOTOR_PORT_PORTPWM, MOTOR_PORT_PINPWM, MOTOR_PORT_CS_ADC);
Actuator actuatorStarboard(&MOTOR_STARBOARD_PORT1, MOTOR_STARBOARD_PIN1, &MOTOR_STARBOARD_PORT2, MOTOR_STARBOARD_PIN2, &MOTOR_STARBOARD_PORTPWM, MOTOR_STARBOARD_PINPWM, MOTOR_STARBOARD_CS_ADC);

//If centerMotor is true, the actuator will be used.  Otherwise, the outputs will.
Actuator actuatorCenter(&MOTOR_CENTER_PORT1, MOTOR_CENTER_PIN1, &MOTOR_CENTER_PORT2, MOTOR_CENTER_PIN2, &MOTOR_CENTER_PORTPWM, MOTOR_CENTER_PINPWM, MOTOR_CENTER_CS_ADC);
Output horn(&MOTOR_CENTER_PORT1, MOTOR_CENTER_PIN1);
Output lights(&MOTOR_CENTER_PORT2, MOTOR_CENTER_PIN2);

//Instantiate LED control objects
Output ledStarboard(&LED_RIGHT_PORT, LED_RIGHT_PIN);
Output ledCenter(&LED_CENTER_PORT, LED_CENTER_PIN);
Output ledPort(&LED_LEFT_PORT, LED_LEFT_PIN);

//The three input buttons.	The constructor for this class takes care of input mode, pullups, etc.
Buttons buttons(&BUTTON1_PORT, BUTTON1_PIN, &BUTTON2_PORT, BUTTON2_PIN, &BUTTON3_PORT, BUTTON3_PIN);

//This cannot be a class variable, since it needs to be accessed by an ISR
SerialAVR serialAvr(115200, 8, 0, 1, 1, 64);		//BLE (UART1), default 115200 baud
#ifdef DEBUG
SerialUSB serialUSB;
#endif

FramedSerialProtocol protocol(64);
FramedSerialMessage request(0, 64);

//These are global config variables, and are loaded from EEPROM in setup()
uint8_t centerMotor = 0x00;
uint8_t demoMode = 0x00;
uint8_t wakeTransferDelay = 0x00;		//This value is in 10ths of a second.

char buf[60];

#ifdef DEBUG
void debug(const char* buf){
	//Send debug message via USB up to ending 0x00 byte
	if (serialUSB.isConnected()){
		for (uint8_t i = 0; i < 60; i++){
			if (buf[i] == 0){
				serialUSB.write((uint8_t) '\r');
				serialUSB.write((uint8_t) '\n');
				serialUSB.write((uint8_t*) buf, i);
				break;	//Stop once we reach the null end of string char
			}
		}
	}

	//Send debug messages to mobile
	FramedSerialMessage m(MSG_DEBUG, 64);
	for (uint8_t i = 0; i < 80; i++){
		m.append(buf[i]);
		if (buf[i] == 0){
			break;	//Stop once we reach the null end of string char
		}
	}
	protocol.write(&serialAvr, &m);
}
#endif

void setup() {
	//Disable watchdog timer
	wdt_disable();

	//Set clock to run at full speed
	clock_prescale_set(clock_div_1);

	// DISABLE JTAG - take control of F port
	MCUCR = _BV(JTD);
	MCUCR = _BV(JTD);

	//We write the magic number at the beginning of the eeprom as a
	// (very primitive) verification that we wrote this data, rather
	// than just being random.
	if (eeprom_read_byte((uint8_t*) EEPROM_OFFSET) == 0x42){
		centerMotor = eeprom_read_byte((uint8_t*) (EEPROM_OFFSET + 1));
		demoMode = eeprom_read_byte((uint8_t*) (EEPROM_OFFSET + 2));
		wakeTransferDelay = eeprom_read_byte((uint8_t*) (EEPROM_OFFSET + 3));
		uint16_t fullExtensionTime = 100 * eeprom_read_byte((uint8_t*) (EEPROM_OFFSET + 4));
		actuatorPort.set_full_extension_time(fullExtensionTime);
		actuatorStarboard.set_full_extension_time(fullExtensionTime);
		actuatorCenter.set_full_extension_time(fullExtensionTime);
	}

	//Add pullups on POT1 ADC pin.
	//Important: This statement assumes that the two pots are both on PORTF (where the ADC number
	// matches the pin number).  If this changes in a future hardware revision, be sure to
	// change this code too!
	PORTF |= _BV(POT1_ADC);
	PORTF |= _BV(POT1_ADC) | _BV(POT2_ADC);		//This would enable pullup for POT2 as well...

	bluetooth_init();

	if (!centerMotor){
		//Set PWM constantly high for horn / light output
		MOTOR_CENTER_PORTPWM |= _BV(MOTOR_CENTER_PINPWM);
	}

	//Flash all lights on solid for 4 seconds to indicate restart.  We also retract both motors during this period.
	ledStarboard.on();
	ledCenter.on();
	ledPort.on();
	ledStarboard.poll(0);
	ledCenter.poll(0);
	ledPort.poll(0);

	//Start retracting motors
	actuatorPort.set_manual_movement(-1);
	actuatorStarboard.set_manual_movement(-1);
	if (centerMotor){
		actuatorCenter.set_extension(100);  //Fully extend center tab
		actuatorCenter.poll(0);
	}
	actuatorPort.poll(0);
	actuatorStarboard.poll(0);

	//Init ADC pins with reference of AVCC (with external cap at AREF).
	uint8_t analog_pins[5];
	analog_pins[POT1_INDEX] = POT1_ADC;
	analog_pins[POT2_INDEX] = POT2_ADC;
	analog_pins[MOTOR_PORT_CS_INDEX] = MOTOR_PORT_CS_ADC;
	analog_pins[MOTOR_STARBOARD_CS_INDEX] = MOTOR_STARBOARD_CS_ADC;
	analog_pins[MOTOR_CENTER_CS_INDEX] = MOTOR_CENTER_CS_ADC;
	analog_init(analog_pins, 5, ANALOG_AVCC);

	software_serial_init(9600);		//GPS, NEMA mode

	_delay_ms(4000);

	//Stop retracting motors
	actuatorPort.set_manual_movement(0);
	actuatorStarboard.set_manual_movement(0);
	if (centerMotor){
		actuatorCenter.poll(4000);
	}
	actuatorPort.poll(4000);
	actuatorStarboard.poll(4000);

	timer_init();

	#ifdef DEBUG
	debug("Startup completed; enabling watchdog timer");
 	#endif
	wdt_enable(WDTO_1S);
}

void loop() {
	//Reset WDT
	wdt_reset();

	//***** State variables *****//

	//Current operation mode
	static uint8_t mode = MODE_READY;

	//Scheduled time to perform a wake transfer operation.
	static uint32_t transferTime = 0;


	//***** Time how long each iteration through the loop takes.	Various poll methods use the elapsed time to control delays. *****//

	static uint32_t last_time = 0;
	static uint32_t currentTime = 0;
	last_time = currentTime;
	currentTime = timer_millis();
	uint32_t elapsedTime = currentTime - last_time;

	//***** Look for new incoming messages from the bluetooth.
	uint8_t cmd = 0x00;
	if (protocol.read(&serialAvr, &request)){
		cmd = request.getCommand();
		#ifdef DEBUG
		snprintf(buf, sizeof(buf), "Message received: Command 0x%02X", cmd);
		debug(buf);
		#endif
	}


	//***** Poll hardware.	This includes starting / stopping actuators, toggling outputs, reading GPS, etc. *****//

	//Actuator movement polls
	actuatorPort.poll(elapsedTime);
	actuatorStarboard.poll(elapsedTime);

	if (centerMotor){
		actuatorCenter.poll(elapsedTime);
	}
	else {
		horn.poll(elapsedTime);
		lights.poll(elapsedTime);
	}

	//Button state + software debouncing
	buttons.poll(elapsedTime);

	//Output polls
	ledStarboard.poll(elapsedTime);
	ledCenter.poll(elapsedTime);
	ledPort.poll(elapsedTime);

	//GPS polls
	gps.poll(elapsedTime);

	static uint8_t pot1Percentage = 0;
	static uint8_t lastPot1Percentage = 0;
	//These are only used if centerMotor is true
	static uint8_t pot2Percentage = 0;
	static uint8_t lastPot2Percentage = 0;

	//Every ~200ms, read the potentiometers to find desired extension percentage (from 75% - 100% for POT1, and from 0% - 100% for POT2).
	static uint32_t lastAdcTime = 0;
	if (currentTime - lastAdcTime >= 200){
		// To combat noise, we read it 8 times and take the average.
		double totalPercentage = 0;
		for (uint8_t i = 0; i < 8; i++){
			totalPercentage += 75 + (analog_read_p(POT1_INDEX) / 40.92);
		}
		pot1Percentage = totalPercentage / 8;
		if (centerMotor){
			totalPercentage = 0;
			for (uint8_t i = 0; i < 8; i++){
				totalPercentage += analog_read_p(POT2_INDEX) / 10.23;
			}
			pot2Percentage = totalPercentage / 8;
		}

		uint16_t currentSense[3];
		currentSense[0] = analog_read_p(MOTOR_PORT_CS_INDEX);
		currentSense[1] = analog_read_p(MOTOR_STARBOARD_CS_INDEX);
		currentSense[2] = analog_read_p(MOTOR_CENTER_CS_INDEX);
		if (currentSense[0] > 0 || currentSense[1] > 0 || currentSense[2] > 0){
			FramedSerialMessage m(MSG_CURRENT_SENSE, 3);
			m.append((uint8_t) (currentSense[0] >> 2));
			m.append((uint8_t) (currentSense[1] >> 2));
			m.append((uint8_t) (currentSense[2] >> 2));
			protocol.write(&serialAvr, &m);
		}

		lastAdcTime = currentTime;
	}

	//Every ~2 seconds, send the mobile client the current program state.  Alternatively,
	// other logic can set lastStateTime to 0 to force it to send immediately (this is
	// done when we know the state has changed, and want to inform the mobile
	// client immediately).
	static uint32_t lastStateTime = 0;
	uint16_t statusTimeout = (mode == MODE_READY ? 2000 : 100);
	if (currentTime - lastStateTime >= statusTimeout){
		FramedSerialMessage m(MSG_STATE, 9);
		m.append(mode);
		m.append(actuatorPort.get_extension());
		m.append(actuatorStarboard.get_extension());
		m.append(centerMotor ? actuatorCenter.get_extension() : 0);
		m.append(pot1Percentage);
		m.append(pot2Percentage);
		m.append(gps.get_locked());
		m.append(gps.get_speed());
		if (transferTime < currentTime){
			m.append(0);
		}
		else {
			m.append((currentTime - transferTime) / 100);	//Send wake transfer time in 10ths of a second
		}
		protocol.write(&serialAvr, &m);
		lastStateTime = currentTime;
	}

	//***** Convert inputs + mode to action (state change definitions) *****//

	//Check the pressed and held state of all three buttons.	This will return non-zero values if a button has just been debounced.
	uint8_t released = buttons.rising_edge();
	uint8_t longpressed = buttons.longpressed();
	uint8_t held = buttons.held();

#ifdef DEBUG
	if (released || longpressed || held){
		snprintf(buf, sizeof(buf), "Release: %d; Long Press: %d; Held: %d", released, longpressed, held);
		debug(buf);
	}
#endif

	//Reset can happen in any mode at any time.
	if (released == _BV(BUTTON_RESET) || cmd == MSG_RESET) {
		#ifdef DEBUG
		debug("Reset");
		#endif
		actuatorPort.set_extension(0);
		actuatorStarboard.set_extension(0);
		if (centerMotor){
			if (pot2Percentage == 0) {
				actuatorCenter.set_extension(0);
				lastPot2Percentage = pot2Percentage;
			}
			else {
				actuatorCenter.set_extension(100);
			}
		}
		transferTime = 0;
		mode = MODE_AUTOMATIC_CHANGE;
	}
	//The mobile device can send MSG_STATE to request the current state be sent immediately.
	else if (cmd == MSG_STATE){
		lastStateTime = 0;
	}
	//The mobile client can ask for current config values at any time, and we immediately respond.
	else if (cmd == MSG_GET_CONFIG){
		FramedSerialMessage m(MSG_GET_CONFIG, 4);
		m.append(centerMotor);
		m.append(demoMode);
		m.append(wakeTransferDelay);
		m.append(actuatorPort.get_full_extension_time() / 100);	//We assume all actuators use the same value...
		protocol.write(&serialAvr, &m);
	}
	//Set config can happen in any mode at any time.
	else if (cmd == MSG_SET_CONFIG && request.getLength() == 4){
		#ifdef DEBUG
		debug("Set config and restart");
		#endif
		eeprom_update_byte((uint8_t*) (EEPROM_OFFSET + 1), request.getData()[0]);	//Center Motor
		eeprom_update_byte((uint8_t*) (EEPROM_OFFSET + 2), request.getData()[1]);	//Demo mode
		eeprom_update_byte((uint8_t*) (EEPROM_OFFSET + 3), request.getData()[2]);	//Wake transfer delay (10ths of a second)
		uint8_t fullExtensionTime = request.getData()[3];
		if (fullExtensionTime < 30) {
			fullExtensionTime = 30;
		}
		else if (fullExtensionTime > 80) {
			fullExtensionTime = 80;
		}
		eeprom_update_byte((uint8_t*) (EEPROM_OFFSET + 4), fullExtensionTime);	//Full extension time (10ths of a second, from 3 to 8 seconds)
		eeprom_update_byte((uint8_t*) EEPROM_OFFSET, 0x42);

		//After writing the data, start an infinite loop and wait for the watchdog timer to reboot.
		while (1){}
	}
	//These four manual adjustment modes can happen regardless of GPS lock
	else if (held == (_BV(BUTTON_SURF_LEFT) | _BV(BUTTON_RESET))){
		#ifdef DEBUG
		snprintf(buf, sizeof(buf), "Hold manual retract port; extension: %d", actuatorPort.get_extension());
		debug(buf);
		#endif

		mode = MODE_MANUAL_RETRACT_PORT;
		actuatorPort.set_manual_movement(-1);
	}
	else if (held == (_BV(BUTTON_SURF_RIGHT) | _BV(BUTTON_RESET))){
		#ifdef DEBUG
		snprintf(buf, sizeof(buf), "Hold manual retract starboard; extension: %d", actuatorStarboard.get_extension());
		debug(buf);
		#endif

		mode = MODE_MANUAL_RETRACT_STARBOARD;
		actuatorStarboard.set_manual_movement(-1);
	}
	else if (held == _BV(BUTTON_SURF_LEFT)){
		#ifdef DEBUG
		snprintf(buf, sizeof(buf), "Hold manual extend port; extension: %d", actuatorPort.get_extension());
		debug(buf);
		#endif

		mode = MODE_MANUAL_EXTEND_PORT;
		actuatorPort.set_manual_movement(1);
	}
	else if (held == _BV(BUTTON_SURF_RIGHT)){
		#ifdef DEBUG
		snprintf(buf, sizeof(buf), "Hold manual extend starboard; extension: %d", actuatorStarboard.get_extension());
		debug(buf);
		#endif

		mode = MODE_MANUAL_EXTEND_STARBOARD;
		actuatorStarboard.set_manual_movement(1);
	}

	//More manual commands which can happen regardless of GPS lock
	else if (cmd == MSG_MANUAL_RETRACT || cmd == MSG_MANUAL_EXTEND){
		if (request.getData()[0] == ACTUATOR_PORT){
			#ifdef DEBUG
			debug("Manual adjust port");
			#endif
			uint8_t extension = actuatorPort.get_extension();
			if (cmd == MSG_MANUAL_RETRACT) extension -= 5;
			else if (cmd == MSG_MANUAL_EXTEND) extension += 5;
			if (extension <= 0) extension = 0;
			else if (extension >= 100) extension = 100;
			actuatorPort.set_extension(extension);
		}
		else if (request.getData()[0] == ACTUATOR_STARBOARD){
			#ifdef DEBUG
			debug("Manual adjust starboard");
			#endif
			uint8_t extension = actuatorStarboard.get_extension();
			if (cmd == MSG_MANUAL_RETRACT) extension -= 5;
			else if (cmd == MSG_MANUAL_EXTEND) extension += 5;
			if (extension <= 0) extension = 0;
			else if (extension >= 100) extension = 100;
			actuatorStarboard.set_extension(extension);
		}
		else if (request.getData()[0] == ACTUATOR_CENTER){
			#ifdef DEBUG
			debug("Manual adjust center");
			#endif
			uint8_t extension = actuatorCenter.get_extension();
			if (cmd == MSG_MANUAL_RETRACT) extension -= 5;
			else if (cmd == MSG_MANUAL_EXTEND) extension += 5;
			if (extension <= 0) extension = 0;
			else if (extension >= 100) extension = 100;
			actuatorCenter.set_extension(extension);
		}
		mode = MODE_AUTOMATIC_CHANGE;
		lastStateTime = 0;		//Send new state to mobile
	}

	//All other modes require a GPS lock and no other concurrent changes
	else if (mode == MODE_READY && gps.get_locked()){
		//Perform wake transfer
		if (transferTime != 0 && transferTime < currentTime && ((actuatorStarboard.get_extension() > 0) ^ (actuatorPort.get_extension() > 0))){		//Execute a wake transfer if one is scheduled for now.
			#ifdef DEBUG
			debug("Wake transfer");
			#endif
			actuatorPort.set_extension(actuatorPort.get_extension() == 0 ? pot1Percentage : 0);
			actuatorStarboard.set_extension(actuatorStarboard.get_extension() == 0 ? pot1Percentage : 0);
			lastPot1Percentage = pot1Percentage;
			transferTime = 0;
			mode = MODE_AUTOMATIC_CHANGE;
		}

		//Initiate launch mode
		else if (cmd == MSG_LAUNCH || longpressed == (_BV(BUTTON_SURF_LEFT) | _BV(BUTTON_SURF_RIGHT))){		//Longpress both surf buttons or send MSG_LAUNCH to initiate launch mode
			#ifdef DEBUG
			debug("Launch mode");
			#endif
			actuatorPort.set_extension(100);
			actuatorStarboard.set_extension(100);
			mode = MODE_AUTOMATIC_CHANGE;
		}

		//Digital trimming of POT_1
		else if (cmd == MSG_POT && request.getData()[0] == POT_1 && ((actuatorStarboard.get_extension() > 0) ^ (actuatorPort.get_extension() > 0))){		//Set new absolute value for the currently deployed tab
			if (actuatorStarboard.get_extension() > 0){
				uint8_t extension = request.getData()[1];
				if (extension <= 70) extension = 70;
				else if (extension >= 100) extension = 100;
				#ifdef DEBUG
				snprintf(buf, sizeof(buf), "Set starboard tab to %d", extension);
				debug(buf);
				#endif
				actuatorStarboard.set_extension(extension);

			}
			else if (actuatorPort.get_extension() > 0){
				uint8_t extension = request.getData()[1];
				if (extension <= 70) extension = 70;
				else if (extension >= 100) extension = 100;
				#ifdef DEBUG
				snprintf(buf, sizeof(buf), "Set port tab to %d", extension);
				debug(buf);
				#endif
				actuatorPort.set_extension(extension);
			}
			mode = MODE_AUTOMATIC_CHANGE;
			lastStateTime = 0;		//Send new state to mobile
		}
		else if (cmd == MSG_POT_TRIM && request.getData()[0] == POT_1 && ((actuatorStarboard.get_extension() > 0) ^ (actuatorPort.get_extension() > 0))){	//Set new relative value for the currently deployed tab
			if (actuatorStarboard.get_extension() > 0){
				#ifdef DEBUG
				debug("Trim starboard tab");
				#endif
				uint8_t extension = actuatorStarboard.get_extension();
				if (request.getData()[1] == DIRECTION_DOWN) extension -= 3;
				else if (request.getData()[1] == DIRECTION_UP) extension += 3;
				if (extension <= 70) extension = 70;
				else if (extension >= 100) extension = 100;
				actuatorStarboard.set_extension(extension);
			}
			else if (actuatorPort.get_extension() > 0){
				#ifdef DEBUG
				debug("Trim port tab");
				#endif
				uint8_t extension = actuatorPort.get_extension();
				if (request.getData()[1] == DIRECTION_DOWN) extension -= 3;
				else if (request.getData()[1] == DIRECTION_UP) extension += 3;
				if (extension <= 70) extension = 70;
				else if (extension >= 100) extension = 100;
				actuatorPort.set_extension(extension);
			}
			mode = MODE_AUTOMATIC_CHANGE;
			lastStateTime = 0;		//Send new state to mobile
		}

		//Initial surf left / surf right
		else if ((released == _BV(BUTTON_SURF_LEFT) || cmd == MSG_SURF_LEFT) && actuatorPort.get_extension() == 0 && actuatorStarboard.get_extension() == 0){	//Starting from a reset, surf left
			#ifdef DEBUG
			debug("Surf Left");
			#endif
			actuatorStarboard.set_extension(pot1Percentage);
			actuatorPort.set_extension(0);
			lastPot1Percentage = pot1Percentage;
			mode = MODE_AUTOMATIC_CHANGE;
		}
		else if ((released == _BV(BUTTON_SURF_RIGHT) || cmd == MSG_SURF_RIGHT) && actuatorPort.get_extension() == 0 && actuatorStarboard.get_extension() == 0){	//Starting from a reset, surf right
			#ifdef DEBUG
			debug("Surf Right");
			#endif
			actuatorStarboard.set_extension(0);
			actuatorPort.set_extension(pot1Percentage);
			lastPot1Percentage = pot1Percentage;
			mode = MODE_AUTOMATIC_CHANGE;
		}

		//This section allows scheduling wake transfers
		else if ((released == _BV(BUTTON_SURF_LEFT) || cmd == MSG_SURF_LEFT) && actuatorPort.get_extension() > 0 && actuatorStarboard.get_extension() == 0){	//If we are currently surfing right and we ask for surf left, schedule a wake transfer.
			#ifdef DEBUG
			debug("Wake transfer (Surf Left)");
			#endif
			transferTime = currentTime + wakeTransferDelay * 100;
		}
		else if ((released == _BV(BUTTON_SURF_RIGHT) || cmd == MSG_SURF_RIGHT) && actuatorPort.get_extension() == 0 && actuatorStarboard.get_extension() > 0){	//If we are currently surfing left and we ask for a surf right, schedule a wake transfer.
			#ifdef DEBUG
			debug("Wake transfer (Surf Right)");
			#endif
			transferTime = currentTime + wakeTransferDelay * 100;
		}
		else if (cmd == MSG_SCHEDULE_WAKE_TRANSFER && ((actuatorStarboard.get_extension() > 0) ^ (actuatorPort.get_extension() > 0))){	//If we are currently surfing left or right (but not launch mode or reset) and we ask for a wake transfer, schedule one.
			#ifdef DEBUG
			debug("Wake transfer");
			#endif
			transferTime = currentTime + wakeTransferDelay * 100;
		}

		//Read physical potentiometer POT_1
		else if (fabs((int16_t) lastPot1Percentage - pot1Percentage) > 1.5){		//Check if the pot has moved more than +/- 1.5% from last setpoint
			if (actuatorPort.get_extension() != 0 && actuatorStarboard.get_extension() == 0){
				#ifdef DEBUG
				snprintf(buf, sizeof(buf), "Trim port tab to %d", pot1Percentage);
				debug(buf);
				#endif
				actuatorPort.set_extension(pot1Percentage);
				lastPot1Percentage = pot1Percentage;
				mode = MODE_AUTOMATIC_CHANGE;
			}
			else if (actuatorPort.get_extension() == 0 && actuatorStarboard.get_extension() != 0){
				#ifdef DEBUG
				snprintf(buf, sizeof(buf), "Trim starboard tab to %d", pot1Percentage);
				debug(buf);
				#endif
				actuatorStarboard.set_extension(pot1Percentage);
				lastPot1Percentage = pot1Percentage;
				mode = MODE_AUTOMATIC_CHANGE;
			}
			else {
				//Nothing is currently extended; just update the last analog value
				lastPot1Percentage = pot1Percentage;
			}
		}
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
int main(){
	setup();
	while(1){
		loop();
	}

	return 0;
}

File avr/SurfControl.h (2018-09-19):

#ifndef SURF_CONTROL_H
#define SURF_CONTROL_H

//Comment out DEBUG definition to hide debug messages
#define DEBUG

//Define the location in EEPROM for the data storage
#define EEPROM_OFFSET	0x100

//Maximum speed (in kts) before automatic retraction
#define MAX_SPEED							13
//Maximum speed for center tab auto extension
#define CENTER_EXTEND_SPEED					6

/*********** INPUT ***********/

//The analog pins connected to the potentiometers
#define POT1_INDEX							0
#define POT1_ADC							1
#define POT2_INDEX							1
#define POT2_ADC							7

//Port / pin definitions for the three physical buttons
#define BUTTON1_PORT						PORTF
#define BUTTON1_PIN							0
#define BUTTON2_PORT						PORTB
#define BUTTON2_PIN							0
#define BUTTON3_PORT						PORTB
#define BUTTON3_PIN							1

/*********** OUTPUT ***********/

// Define Misc. Output Pins
//Left is LED3 in schematic
#define LED_LEFT_PORT						PORTB
#define LED_LEFT_PIN						7
//Center is LED2 in schematic
#define LED_CENTER_PORT						PORTB
#define LED_CENTER_PIN						3
//Right is LED1 in schematic
#define LED_RIGHT_PORT						PORTB
#define LED_RIGHT_PIN						2

// Define Motor Driver Pins
#define MOTOR_PORT_PORT1					PORTE
#define MOTOR_PORT_PIN1						2
#define MOTOR_PORT_PORT2					PORTC
#define MOTOR_PORT_PIN2						7
#define MOTOR_PORT_PORTPWM					PORTC
#define MOTOR_PORT_PINPWM					6
#define MOTOR_PORT_CS_INDEX					2
#define MOTOR_PORT_CS_ADC					4

#define MOTOR_STARBOARD_PORT1				PORTB
#define MOTOR_STARBOARD_PIN1				6
#define MOTOR_STARBOARD_PORT2				PORTB
#define MOTOR_STARBOARD_PIN2				5
#define MOTOR_STARBOARD_PORTPWM				PORTB
#define MOTOR_STARBOARD_PINPWM				4
#define MOTOR_STARBOARD_CS_INDEX			3
#define MOTOR_STARBOARD_CS_ADC				5

#define MOTOR_CENTER_PORT1					PORTD
#define MOTOR_CENTER_PIN1					7
#define MOTOR_CENTER_PORT2					PORTD
#define MOTOR_CENTER_PIN2					6
#define MOTOR_CENTER_PORTPWM				PORTD
#define MOTOR_CENTER_PINPWM					4
#define MOTOR_CENTER_CS_INDEX				4
#define MOTOR_CENTER_CS_ADC					6



//Available modes
#define MODE_READY							0
#define MODE_AUTOMATIC_CHANGE				1
#define MODE_MANUAL_RETRACT_PORT			2
#define MODE_MANUAL_RETRACT_STARBOARD		3
#define MODE_MANUAL_EXTEND_PORT				4
#define MODE_MANUAL_EXTEND_STARBOARD		5


//Available actuator values; can be used for messages with [Actuator] data bytes.
#define ACTUATOR_PORT						0x01
#define ACTUATOR_STARBOARD					0x02
#define ACTUATOR_CENTER						0x03

//Available directions; can be used for message with [Direction] data bytes
#define DIRECTION_DOWN						0x01
#define DIRECTION_UP						0x02

//Available potentiometers; can be used for message with [Pot Index] data bytes
#define POT_1								0x01
#define POT_2								0x02

//Available messages

//No data byte (command only)
//Use this message to reset the tabs to the fully retracted position.
#define MSG_RESET						0x01
//Use this message to put the tabs into launch mode (fully extended)
#define MSG_LAUNCH						0x02
//Use these messages to enable SURF_LEFT or SURF_RIGHT modes.  Must be sent
// from fully retracted mode.
#define MSG_SURF_LEFT					0x03
#define MSG_SURF_RIGHT					0x04
//One data byte: [Actuator]
//Use these messages to manually retract / extend the tabs.  Each time it is
// sent it adjusts by 5% up or down.
#define MSG_MANUAL_RETRACT				0x05
#define MSG_MANUAL_EXTEND				0x06
//Two data bytes: [Pot Index][Pot Value].  Use this message to set a new
// value for the digital potentiometer.  Values can be between 75 and 100
// for POT_1, and between 0 and 100 for POT_2.
#define MSG_POT							0x07
//One data byte: [Pot Index][Direction].  Use this message to perform a digital adjustment
// of the potentiometer relative to where it is now.  PotIndex is either POT_1 or POT_2.
// Direction is either DIRECTION_RETRACT or DIRECTION_EXTEND.
#define MSG_POT_TRIM					0x08
//No data.  The SCHEDULE_WAKE_TRANSFER message is only valid if currently in one of SURF_RIGHT / SURF_LEFT modes.
#define MSG_SCHEDULE_WAKE_TRANSFER		0x09
//X data bytes containing ASCII text.  This is sent from the MCU to the
// mobile device to communicate debug messages.
#define MSG_DEBUG						0x0A
//Data bytes: [Mode][PortActuatorValue][StarboardActuatorValue][CenterActuatorValue][Pot1Value][Pot2Value][GPS locked][GPSspeed][WakeTransferTimer]
// This is sent from the MCU to the mobile device, and contains all the program state, so that the mobile app can update the UI
// The mobile device can send this message (no need for any data bytes) to request that the MCU sends the MSG_SSTATE immediately.
#define MSG_STATE						0x0B
//Data bytes: [PortCS][StarboardCS][CenterCS]
// This is sent from the MCU to the mobile device to send the current sense values.  The
// current values are each 8 bit unsigned integers (the 8 MSB of the 10 bit analog values).
#define MSG_CURRENT_SENSE				0x0C
//The mobile client sends this to request current config values.  No data bytes.
//The MCU responds with the same message with current config values.  3 data bytes,
// same order and semantics as MSG_SET_CONFIG.
#define MSG_GET_CONFIG					0x0D
//Data bytes: [CenterMotor][DemoMode][WakeTransferDelay][FullExtensionTime]
//Write the CenterMotor and DemoMode config variables to EEPROM and reset the MCU.
// CenterMotor and DemoMode are boolean (1 = Enabled / True, 0 = Disabled / False).
// WakeTransferDelay is uint8_t, expressed in 10ths of a second (i.e. a value of 25 = 2.5 seconds)
// FullExtensionTime is uint8_t, expressed in 10ths of a second (i.e. 35 = 3.5 seconds).  This
// value must be between 30 and 80 (3.0 and 8.0 seconds).
#define MSG_SET_CONFIG					0x0E

//One data byte: [LegacyCommand] single data byte containing the legacy command
#define MSG_LEGACY						0xFF



//Used to keep the setup() method cleaner
void bluetooth_init();

#endif

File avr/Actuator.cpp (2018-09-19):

#include "Actuator.h"

Actuator::Actuator(volatile uint8_t *port1, uint8_t pin1, volatile uint8_t *port2, uint8_t pin2, volatile uint8_t *portPwm, uint8_t pinPwm, uint8_t csAdc){
	//Store the port / pin values
	this->port1 = port1;
	this->pin1 = pin1;
	this->port2 = port2;
	this->pin2 = pin2;
	this->portPwm = portPwm;
	this->pinPwm = pinPwm;
	this->csAdc = csAdc;

	fullExtensionTime = 3500;

	//Set to logic low
	*port1 &= ~_BV(pin1);
	*port2 &= ~_BV(pin2);
	*portPwm &= ~_BV(pinPwm);

	//Set DDR to output for all three pins
	*(port1 - 0x1) |= _BV(pin1);
	*(port2 - 0x1) |= _BV(pin2);
	*(portPwm - 0x1) |= _BV(pinPwm);
}

void Actuator::poll(uint16_t elapsed_time){
	//If both extend and retract are finished, and manual movement is not enabled, then turn off all the pins
	if (extend_time <= 0 && retract_time <= 0 && manual_movement == 0){
		*port1 &= ~_BV(pin1);
		*port2 &= ~_BV(pin2);
		*portPwm |= _BV(pinPwm);

		//Reset the timers to zero.	This will be a nop EXCEPT when poll is called for the first time
		// after the timers going negative (signalling completion).
		extend_time = 0;
		retract_time = 0;
	}
	else if (extend_time > 0 || manual_movement > 0){
		//Set pin1 low, pin2 high, and pwm high
		*port1 &= ~_BV(pin1);
		*port2 |= _BV(pin2);
		*portPwm |= _BV(pinPwm);

		if (manual_movement == 0) extend_time -= elapsed_time;
		total_extension_time += elapsed_time;
	}
	else if (retract_time > 0 || manual_movement < 0){
		//Set pin1 high, pin2 low, and pwm high
		*port1 |= _BV(pin1);
		*port2 &= ~_BV(pin2);
		*portPwm |= _BV(pinPwm);

		if (manual_movement == 0) retract_time -= elapsed_time;
		total_extension_time -= elapsed_time;
	}

	//If we have tried to overrun the extension, then limit it to the range 0..fullExtensionTime.	This will (somewhat) allow for recalibration of
	// the setpoint over time, assuming that we try to reach max or min extension during operation.
	if (total_extension_time <= 0) total_extension_time = 0;
	else if (total_extension_time >= fullExtensionTime) total_extension_time = fullExtensionTime;
}

void Actuator::set_extension(int8_t percent){
	if (percent > 100) percent = 100;
	else if (percent < 0) percent = 0;

	manual_movement = 0;	//Stop any ongoing manual movement

	uint8_t currently_moving = 0;
	if (extend_time != 0 || retract_time != 0) currently_moving = 1;

	int32_t target_time = ((int32_t) fullExtensionTime * percent) / 100;
	if (target_time < total_extension_time){
		retract_time = total_extension_time - target_time;
		extend_time = 0;
	}
	else {
		extend_time = target_time - total_extension_time;
		retract_time = 0;
	}

	//If we are just starting the movement, add an extra bit of time to compensate for motor spin-up.
	if (!currently_moving){
		if (extend_time > 0) total_extension_time -= STARTUP_TIME;
		else if (retract_time > 0) total_extension_time += STARTUP_TIME;
	}

	//Throw some extra time to extend / retract if we are going right to the end.  This can help
	// to allow users to re-set the accumulated error over time.
	if (extend_time > 0 && percent == 100) extend_time += 2500;
	else if (retract_time > 0 && percent == 0) retract_time += 2500;
}

void Actuator::set_manual_movement(int8_t movement){
	manual_movement = movement;
}

uint8_t Actuator::get_extension(){
	int16_t result = (total_extension_time * 100) / fullExtensionTime;
	if (result < 5) return 0;
	if (result > 98) return 100;
	return result;
}

void Actuator::adjust_extension(int8_t percent){
	set_extension(get_extension() + percent);
}

int32_t Actuator::get_outstanding_time(){
	if (extend_time > 0) return extend_time;
	else if (retract_time > 0) return retract_time * -1;
	else return 0;
}

uint32_t Actuator::get_full_extension_time(){
	return fullExtensionTime;
}
void Actuator::set_full_extension_time(uint16_t newFullExtensionTime){
	if (newFullExtensionTime < 3000) {
		newFullExtensionTime = 3000;
	}
	else if (newFullExtensionTime > 8000){
		newFullExtensionTime = 8000;
	}

	fullExtensionTime = newFullExtensionTime;
}
